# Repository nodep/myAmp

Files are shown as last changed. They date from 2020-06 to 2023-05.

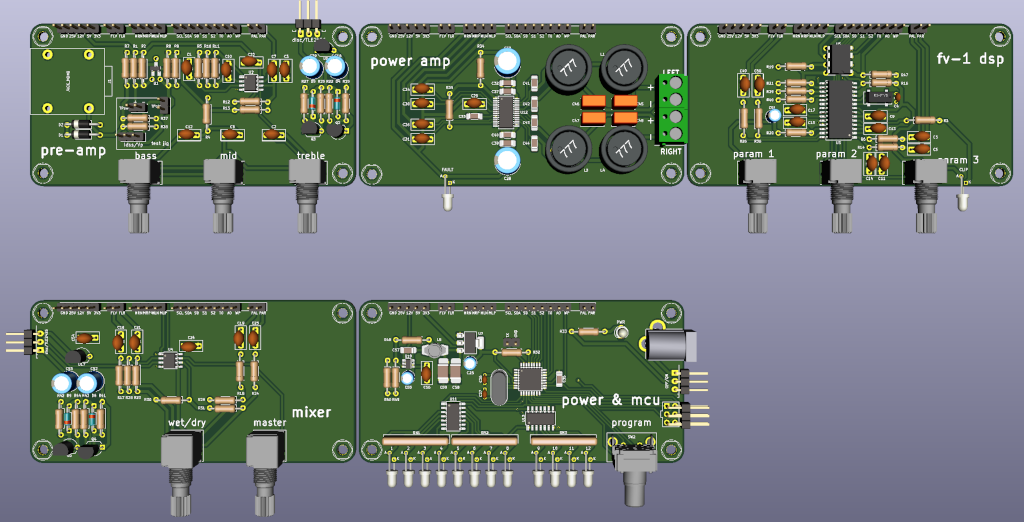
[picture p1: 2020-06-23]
docs/3drender.png

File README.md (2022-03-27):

# modulo2

What started as an idea to upgrade the guts of a practice guitar amplifier (Marshall Valvestate 8010), has evolved into a stereo guitar amplifier with effects. The current prototype is housed in a guitar pedal box (119 x 93.5 x 56.5mm). It has a modular design with the preamp, the effects board, and a stereo power amp. These modules are split into their own PCBs.

### The preamp

It is based on ESP's project 27 (https://sound-au.com/project27.htm). I have only used the preamp from this project and I have made a few changes:

- The overdrive section is changed to work as protection and limit the output to 3.3V. This is needed for the inputs of the DSP chip in the effects section (max input of FV-1 is 3.3V).
- The zener diode rail splitter is changed to a TL2426. Reasons being a smaller footprint and much lower power consumption.
- The total gain has been reduced on every stage.
- The tone control values have changed to a more Fender-like sound.

### The effects

The effects sections is based on a Spin semiconductor's FV-1 DSP chip. The chip has 8 built-in effects and the ability to read 8 more effects from an external EEPROM. This was extended using a microcontroller (ATmega328p) to up to 50 external effects which are read from the microcontroller's flash memory. The board also has a dry/wet mixer, a master volume. The microcontroller has a driverless USB bootloader which allows easier firmware updates and DSP program modification. A rotary encoder allows for FV-1 program selection and changing the input clock frequency of the FV-1. Some of the FV-1 programs work as a mono input and produce a stereo output with one channel outputing a slightly different signal to the other creating a stereo effect from a mono preamp input. The microcontroller oversees the power section to avoid audible pops during the power-up and power-down.

### The power amp

The power section is based on a TPA3220 in a stereo configuration. I have not tested it fully yet, but it should be able to output up to 60W into 4Ω per channel. It is a Class-D amp bringing high efficiency (around 90%) and very low distortion and noise. The TPA3220 chip has an integrated preamp with a selectable gain (4 distinct levels) making the full range of the master volume useful for quiter practice and louder performance levels.

The PCBs for the final prototype have been send to the fab.

Stay tuned for results!

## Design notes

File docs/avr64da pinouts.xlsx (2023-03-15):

VQFN64 TQFP64 | VQFN48 TQFP48 | VQFN32 TQFP32 | SPDIP28 SOIC28 SSOP28 | Pin name | Special | ADC0 | PTC | ACn | DAC0 | ZCDn | USARTn | SPIn | TWIn | TCA0 | TCA1 | TCBn | TCDn | EVSYS | CCL-LUTn
62 | 44 | 30 | 22 | PA0 | EXTCLK |  | X0/Y0 |  |  |  | 0,TxD |  |  | WO0 |  |  |  |  | 0,IN0
63 | 45 | 31 | 23 | PA1 |  |  | X1/Y1 |  |  |  | 0,RxD |  |  | WO1 |  |  |  |  | 0,IN1
64 | 46 | 32 | 24 | PA2 | TWI |  | X2/Y2 |  |  |  | 0,XCK |  | 0,SDA(H) | WO2 |  | 0,WO |  | EVOUTA | 0,IN2
1 | 47 | 1 | 25 | PA3 | TWI |  | X3/Y3 |  |  |  | 0,XDIR |  | 0,SCL(H) | WO3 |  | 1,WO |  |  | 0,OUT
2 | 48 | 2 | 26 | PA4 |  |  | X4/Y4 |  |  |  | 0,TxD (alt) | 0,MOSI |  | WO4 |  |  | 0,WOA
3 | 1 | 3 | 27 | PA5 |  |  | X5/Y5 |  |  |  | 0,RxD (alt) | 0,MISO |  | WO5 |  |  | 0,WOB
4 | 2 | 4 | 28 | PA6 |  |  | X6/Y6 |  |  |  | 0,XCK (alt) | 0,SCK |  |  |  |  | 0,WOC |  | 0,OUT (alt)
5 | 3 | 5 | 1 | PA7 | CLKOUT |  | X7/Y7 | 0,OUT 1,OUT 2,OUT |  | 0,OUT 1,OUT 2,OUT | 0,XDIR (alt) | 0,SS |  |  |  |  | 0,WOD | EVOUTA (alt)
6 |  |  |  | VDD
7 |  |  |  | GND
8 | 4 |  |  | PB0 |  |  | X8/Y8 |  |  |  | 3,TxD |  |  | WO0 (alt) | WO0 |  |  |  | 4,IN0
9 | 5 |  |  | PB1 |  |  | X9/Y9 |  |  |  | 3,RxD |  |  | WO1 (alt) | WO1 |  |  |  | 4,IN1
10 | 6 |  |  | PB2 |  |  | X10/Y10 |  |  |  | 3,XCK |  | 1,SDA(H) (alt) | WO2 (alt) | WO2 |  |  | EVOUTB | 4,IN2
11 | 7 |  |  | PB3 |  |  | X11/Y11 |  |  |  | 3,XDIR |  | 1,SCL(H) (alt) | WO3 (alt) | WO3 |  |  |  | 4,OUT
12 | 8 |  |  | PB4 |  |  | X12/Y12 |  |  |  | 3,TxD (alt) | 1,MOSI (alt) |  | WO4 (alt) | WO4 | 2,WO (alt) | 0,WOA (alt)
13 | 9 |  |  | PB5 |  |  | X13/Y13 |  |  |  | 3,RxD (alt) | 1,MISO (alt) |  | WO5 (alt) | WO5 | 3,WO | 0,WOB (alt)
14 |  |  |  | PB6 |  |  | X14/Y14 |  |  |  | 3,XCK (alt) | 1,SCK (alt) | 1,SDA(C) (alt) |  |  |  | 0,WOC (alt) |  | 4,OUT (alt)
15 |  |  |  | PB7 |  |  | X15/Y15 |  |  |  | 3,XDIR (alt) | 1,SS (alt) | 1,SCL(C) (alt) |  |  |  | 0,WOD (alt) | EVOUTB (alt)
16 | 10 | 6 | 2 | PC0 |  |  |  |  |  |  | 1,TxD | 1,MOSI |  | WO0 (alt) |  | 2,WO |  |  | 1,IN0
17 | 11 | 7 | 3 | PC1 |  |  |  |  |  |  | 1,RxD | 1,MISO |  | WO1 (alt) |  | 3,WO (alt) |  |  | 1,IN1
18 | 12 | 8 | 4 | PC2 | TWI |  |  |  |  |  | 1,XCK | 1,SCK | 0,SDA(H) (alt) | WO2 (alt) |  |  |  | EVOUTC | 1,IN2
19 | 13 | 9 | 5 | PC3 | TWI |  |  |  |  |  | 1,XDIR | 1,SS | 0,SCL(H) (alt) | WO3 (alt) |  |  |  |  | 1,OUT
20 | 14 |  |  | VDD
21 | 15 |  |  | GND
22 | 16 |  |  | PC4 |  |  |  |  |  |  | 1,TxD (alt) | 1,MOSI (alt) |  | WO4 (alt) | WO0 (alt)
23 | 17 |  |  | PC5 |  |  |  |  |  |  | 1,RxD (alt) | 1,MISO (alt) |  | WO5 (alt) | WO1 (alt)
24 | 18 |  |  | PC6 |  |  |  | 0,OUT (alt) 1,OUT (alt) 2,OUT (alt) |  |  | 1,XCK (alt) | 1,SCK (alt) | 0,SDA(C) |  | WO2 (alt) | 4,WO (alt) |  |  | 1,OUT (alt)
25 | 19 |  |  | PC7 |  |  |  |  |  | 0,OUT (alt) 1,OUT (alt) 2,OUT (alt) | 1,XDIR (alt) | 1,SS (alt) | 0,SCL(C) |  |  |  |  | EVOUTC (alt)
26 | 20 | 10 | 6 | PD0 |  | AIN0 | X16/Y16 | 0,AINN1 1,AINN1 2,AINN1 |  |  |  |  |  | WO0 (alt) |  |  |  |  | 2,IN0
27 | 21 | 11 | 7 | PD1 |  | AIN1 | X17/Y17 |  |  | 0,ZCIN |  |  |  | WO1 (alt) |  |  |  |  | 2,IN1
28 | 22 | 12 | 8 | PD2 |  | AIN2 | X18/Y18 | 0,AINP0 1,AINP0 2,AINP0 |  |  |  |  |  | WO2 (alt) |  |  |  | EVOUTD | 2,IN2
29 | 23 | 13 | 9 | PD3 |  | AIN3 | X19/Y19 | 0,AINN0 1,AINP1 |  |  |  |  |  | WO3 (alt) |  |  |  |  | 2,OUT
30 | 24 | 14 | 10 | PD4 |  | AIN4 | X20/Y20 | 1,AINP2 2,AINP1 |  |  |  |  |  | WO4 (alt)
31 | 25 | 15 | 11 | PD5 |  | AIN5 | X21/Y21 | 1,AINN0 |  |  |  |  |  | WO5 (alt)
32 | 26 | 16 | 12 | PD6 |  | AIN6 | X22/Y22 | 0,AINP3 1,AINP3 2,AINP3 0,AINN2 | VOUT |  |  |  |  |  |  |  |  |  | 2,OUT (alt)
33 | 27 | 17 | 13 | PD7 | VREFA | AIN7 | X23/Y23 | 1,AINN2 2,AINN0/AINN2 |  |  |  |  |  |  |  |  |  | EVOUTD (alt)
34 | 28 | 18 | 14 | AVDD
35 | 29 | 19 | 15 | GND
36 | 30 |  |  | PE0 |  | AIN8 | X24/Y24 | 0,AINP1 |  |  | 4,TxD | 0,MOSI (alt) |  | WO0 (alt)
37 | 31 |  |  | PE1 |  | AIN9 | X25/Y25 | 2,AINP2 |  |  | 4,RxD | 0,MISO (alt) |  | WO1 (alt)
38 | 32 |  |  | PE2 |  | AIN10 | X26/Y26 | 0,AINP2 |  |  | 4,XCK | 0,SCK (alt) |  | WO2 (alt) |  |  |  | EVOUTE
39 | 33 |  |  | PE3 |  | AIN11 | X27/Y27 |  |  | 1,ZCIN | 4,XDIR | 0,SS (alt) |  | WO3 (alt)
40 |  |  |  | PE4 |  | AIN12 | X28/Y28 |  |  |  | 4,TxD (alt) |  |  | WO4 (alt) | WO0 (alt)
41 |  |  |  | PE5 |  | AIN13 | X29/Y29 |  |  |  | 4,RxD (alt) |  |  | WO5 (alt) | WO1 (alt)
42 |  |  |  | PE6 |  | AIN14 | X30/Y30 |  |  |  | 4,XCK (alt) |  |  |  | WO2 (alt)
43 |  |  |  | PE7 |  | AIN15 | X31/Y31 |  |  | 2,ZCIN | 4,XDIR (alt) |  |  |  |  |  |  | EVOUTE (alt)
44 | 34 | 20 | 16 | PF0 | XTAL32K1 | AIN16 | X32/Y32 |  |  |  | 2,TxD |  |  | WO0 (alt) |  |  | 0,WOA (alt) |  | 3,IN0
45 | 35 | 21 | 17 | PF1 | XTAL32K2 | AIN17 | X33/Y33 |  |  |  | 2,RxD |  |  | WO1 (alt) |  |  | 0,WOB (alt) |  | 3,IN1
46 | 36 | 22 |  | PF2 | TWI | AIN18 | X34/Y34 |  |  |  | 2,XCK |  | 1,SDA(H) | WO2 (alt) |  |  | 0,WOC | EVOUTF | 3,IN2
47 | 37 | 23 |  | PF3 | TWI | AIN19 | X35/Y35 |  |  |  | 2, XDIR |  | 1,SCL(H) | WO3 (alt) |  |  | 0,WOD |  | 3,OUT
48 | 38 | 24 |  | PF4 |  | AIN20 | X36/Y36 |  |  |  | 2, TxD |  |  | WO4 (alt) |  | 0,WO (alt)
49 | 39 | 25 |  | PF5 |  | AIN21 | X37/Y37 |  |  |  | 2, RxD |  |  | WO5 (alt) |  | 1,WO (alt)
50 | 40 | 26 | 18 | PF6 | RESET
51 | 41 | 27 | 19 | UPDI
52 |  |  |  | PG0 |  |  | X40/Y40 |  |  |  | 5,TxD |  |  | WO0 (alt) | WO0 (alt) |  |  |  | 5,IN0
53 |  |  |  | PG1 |  |  | X41/Y41 |  |  |  | 5,RxD |  |  | WO1 (alt) | WO1 (alt) |  |  |  | 5,IN1
54 |  |  |  | PG2 |  |  | X42/Y42 |  |  |  | 5,XCK |  |  | WO2 (alt) | WO2 (alt) |  |  | EVOUTG | 5,IN2
55 |  |  |  | PG3 |  |  | X43/Y43 |  |  |  | 5,XDIR |  |  | WO3 (alt) | WO3 (alt) | 4,WO |  |  | 5,OUT
56 | 42 | 28 | 20 | VDD
57 | 43 | 29 | 21 | GND
58 |  |  |  | PG4 |  |  | X44/Y44 |  |  |  | 5,TxD (alt) | 0,MOSI (alt) |  | WO4 (alt) | WO4 (alt) |  | 0,WOA (alt)
59 |  |  |  | PG5 |  |  | X45/Y45 |  |  |  | 5,RxD (alt) | 0,MISO (alt) |  | WO5 (alt) | WO5 (alt) |  | 0,WOB (alt)
60 |  |  |  | PG6 |  |  | X46/Y46 |  |  |  | 5,XCK (alt) | 0,SCK (alt) |  |  |  |  | 0,WOC (alt) |  | 5,OUT (alt)
61 |  |  |  | PG7 |  |  | X47/Y47 |  |  |  | 5,XDIR (alt) | 0,SS (alt) |  |  |  |  | 0,WOD (alt) | EVOUTG (alt)

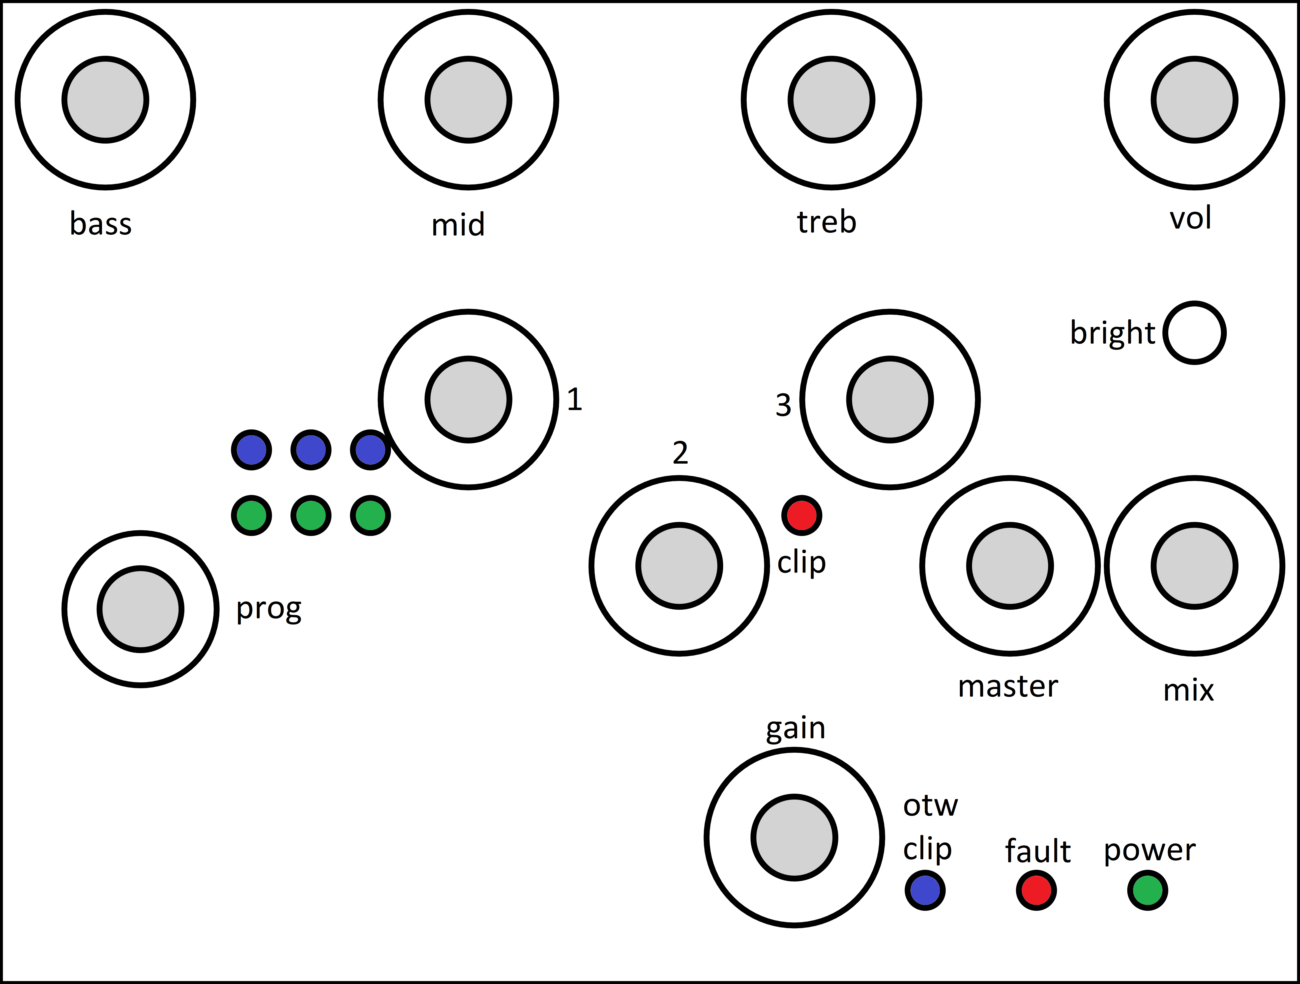
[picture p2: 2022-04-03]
docs/in_pedal_render.png

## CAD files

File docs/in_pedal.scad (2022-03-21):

$fn = 80;

pcb_thick = 1.6;
pcb_width = 105;
pcb_height = 47;
led_r = 3;
led_l = 8;

pot_shaft = 7;
pot_shaft_offset = 6.3;
pot_shaft_len = 6;
pot_depth = 7.05;
pot_height = 11.3;
pot_width = 9.5;
pot_knob_r = 15;

switch_shaft = 5;
switch_shaft_offset = 12;
switch_shaft_len = 12;

rotenc_shaft_r = 7;
rotenc_shaft_l = 15;
rotenc_knob_r = 13;

gain_sel_shaft_r = 7;
gain_sel_shaft_l = 15;

module pcb_blank()
{
	cube([pcb_width, pcb_height, pcb_thick]);
}

module pot_up(pos)
{
	translate([pos - pot_width/2, pcb_height - pot_depth, pcb_thick])
	{
		cube([pot_width, pot_depth, pot_height]);
		
		translate([pot_width/2, pot_shaft_len + pot_depth, pot_shaft_offset])
			rotate([90, 0, 0])
				difference()
				{
					cylinder(pot_shaft_len, pot_knob_r / 2, pot_knob_r / 2);
					cylinder(pot_shaft_len, pot_shaft / 2, pot_shaft / 2);
				}
	}
}

module pot_down(pos)
{
	translate([pos - pot_width/2, pcb_height - pot_depth, -pot_height])
	{
		cube([pot_width, pot_depth, pot_height]);
		
		translate([pot_width/2, pot_shaft_len + pot_depth, pot_height - pot_shaft_offset])
			rotate([90, 0, 0])
				difference()
				{
					cylinder(pot_shaft_len, pot_knob_r / 2, pot_knob_r / 2);
					cylinder(pot_shaft_len, pot_shaft / 2, pot_shaft / 2);
				}
	}
}

module switch_down(pos)
{
	translate([pos, pcb_height + switch_shaft_len / 2, -switch_shaft_offset])
		rotate([90, 0, 0])
			cylinder(switch_shaft_len, switch_shaft / 2, switch_shaft / 2);
}

module led_up(x, off)
{
	translate([x, pcb_height + led_l / 2, pcb_thick + off])
		rotate([90, 0, 0])
			cylinder(led_l, led_r / 2, led_r / 2);
}

module led_down(x, off)
{
	translate([x, pcb_height + led_l / 2, -off])
		rotate([90, 0, 0])
			cylinder(led_l, led_r / 2, led_r / 2);
}

module rotenc_shaft_down(x)
{
	translate([x, pcb_height + rotenc_shaft_l / 2, -10])
		rotate([90, 0, 0])
			difference()
			{
				cylinder(rotenc_shaft_l, rotenc_knob_r / 2, rotenc_knob_r / 2);
				cylinder(rotenc_shaft_l, rotenc_shaft_r / 2, rotenc_shaft_r / 2);
			}
}

module gain_sel_shaft_down(x)
{
	translate([x, pcb_height + gain_sel_shaft_l / 2, pcb_thick + 6.5])
		rotate([90, 0, 0])
			difference()
			{
				cylinder(gain_sel_shaft_l, pot_knob_r / 2, pot_knob_r / 2);
				cylinder(gain_sel_shaft_l, gain_sel_shaft_r / 2, gain_sel_shaft_r / 2);
			}
}

module pcb_pa27()
{
	pcb_blank();

	pot_up( 6);
	pot_up(37);
	pot_up(68);
	pot_up(99);
	
	switch_down(6);
}

module pcb_fv1()
{
	pcb_blank();

	pot_down(6);
	pot_down(21.755);
	pot_up(32);
	pot_down(50);
	pot_up(68);
	
	// clip
	led_down(39.535, 2);
	
	// program
	led_down(76.365, 2);
	led_down(81.445, 2);
	led_down(86.525, 2);
	led_up(76.365, 2);
	led_up(81.445, 2);
	led_up(86.525, 2);
	
	rotenc_shaft_down(96);
}

module pcb_powamp()
{
	pcb_blank();
	
	led_up(10, 2);
	led_up(19.5, 2);
	led_up(29, 2);

	gain_sel_shaft_down(40.17);
}

projection(cut = true)
{
	translate([-20, 0, 0])
		difference()
		{
			translate([-3, -42, -0.8])
				cube([111, 84, pcb_thick]);

			rotate([90, 0, 0])
				translate([0, -48, 0])
				{
					translate([0, 0, 24 + 1.6])
						pcb_pa27();

					translate([0, 0, 0])
						pcb_fv1();

					translate([0, 0, -36 - 1.6])
						pcb_powamp();
				}
		}
}

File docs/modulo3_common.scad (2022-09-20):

module top()
{
	difference()
	{
		top_offset = sin(angle) * thick;

		rotate([-90, 0, 0])
			linear_extrude(baffle_size + thick*2)
				polygon([	[0, 0],
							[0, thick],
							[in_depth - offset, thick],
							[in_depth - offset - top_offset, 0]]);

		translate([0, thick + (baffle_size - ctr_width) / 2, -1 - thick])
			cube([ctr_depth, ctr_width, thick + 2]);
	}
}

module baffle()
{
	difference()
	{
		cube([baffle_thick, baffle_size, baffle_size]);

		translate([-1, baffle_size/2, baffle_size/2])
			rotate([0, 90, 0])
				cylinder(baffle_thick + 2, speaker_hole, speaker_hole);
	}
}

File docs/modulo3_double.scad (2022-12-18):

include <modulo3_common.scad>

$fn = 120;

thick = 18;
baffle_thick = 10;
baffle_size = 330;
in_depth = 280;
speaker_hole = 231/2;

ctr_width = 200;
ctr_depth = 90;
ctr_height = 70;

angle = 15;

up_back_height = 140;
low_back_height = 140;

up_height	= cos(angle) * baffle_size;
offset		= sin(angle) * baffle_size;
in_height	= up_height + baffle_size;

vol_side	= (in_height * in_depth - up_height * offset / 2) * thick;
vol_top		= ((in_depth - offset) * (baffle_size + thick*2) - (ctr_depth * ctr_width)) * thick;
vol_bottom	= in_depth * (baffle_size + thick*2) * thick;
vol_baffle	= (baffle_size * baffle_size - speaker_hole * speaker_hole * 3.1416) * baffle_thick;
vol_separat	= in_depth * baffle_size * baffle_thick;
vol_up_back	= (baffle_size * up_back_height - ctr_width * ctr_height) * thick;
vol_low_back = baffle_size * low_back_height * thick;
vol_all		= (vol_side*2 + vol_top + vol_bottom + vol_baffle * 2 + vol_separat + vol_low_back + vol_up_back) / 1000;

echo("******************************");
echo("volume cm3 = ", vol_all);
echo("pine kg = ", vol_all * 0.52 / 1000);
echo("size: ", baffle_size + thick*2, in_height + thick*2, in_depth);

translate([0, baffle_size + thick*2, 0])
	side();

translate([0, thick, 0])
	side();

// bottom
translate([0, 0, -thick])
	cube([in_depth, baffle_size + thick*2, thick]);

translate([0, 0, in_height + thick])
	top();

// lower baffle
translate([in_depth - baffle_thick*2, thick, 0])
	baffle();

// upper baffle
translate([in_depth - baffle_thick*2, thick, baffle_size - 1.5])
	rotate([0, -angle, 0])
		baffle();

// middle separator
translate([0, thick, baffle_size])
	cube([in_depth - thick, baffle_size, baffle_thick]);

// lower back
translate([0, thick, 0])
	cube([thick, baffle_size, low_back_height]);

translate([0, thick, in_height - up_back_height])
	upper_back();

module upper_back()
{
	difference()
	{
		cube([thick, baffle_size, up_back_height]);
		
		translate([-1, (baffle_size - ctr_width) / 2, up_back_height - ctr_height])
			cube([thick + 2, ctr_width, ctr_height]);
	}
}

module side()
{
	rotate([90, 0, 0])
		linear_extrude(thick)
			polygon([	[0, 0],
						[in_depth, 0],
						[in_depth, baffle_size],
						[in_depth - offset, in_height],
						[0, in_height]]);
}

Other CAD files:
docs/modulo3_single.scad

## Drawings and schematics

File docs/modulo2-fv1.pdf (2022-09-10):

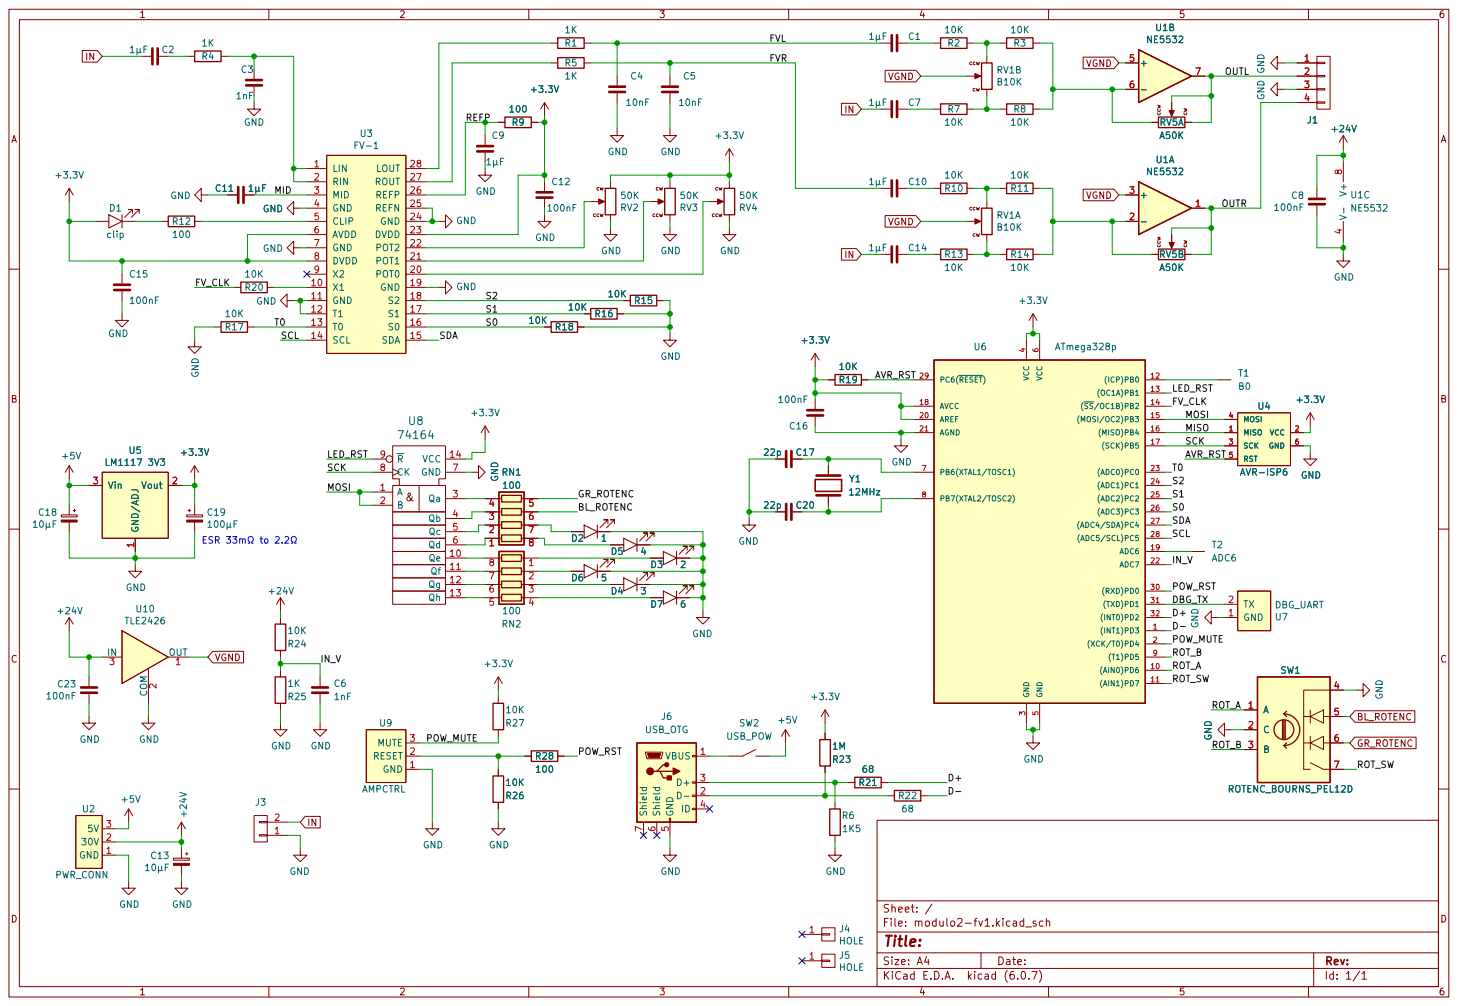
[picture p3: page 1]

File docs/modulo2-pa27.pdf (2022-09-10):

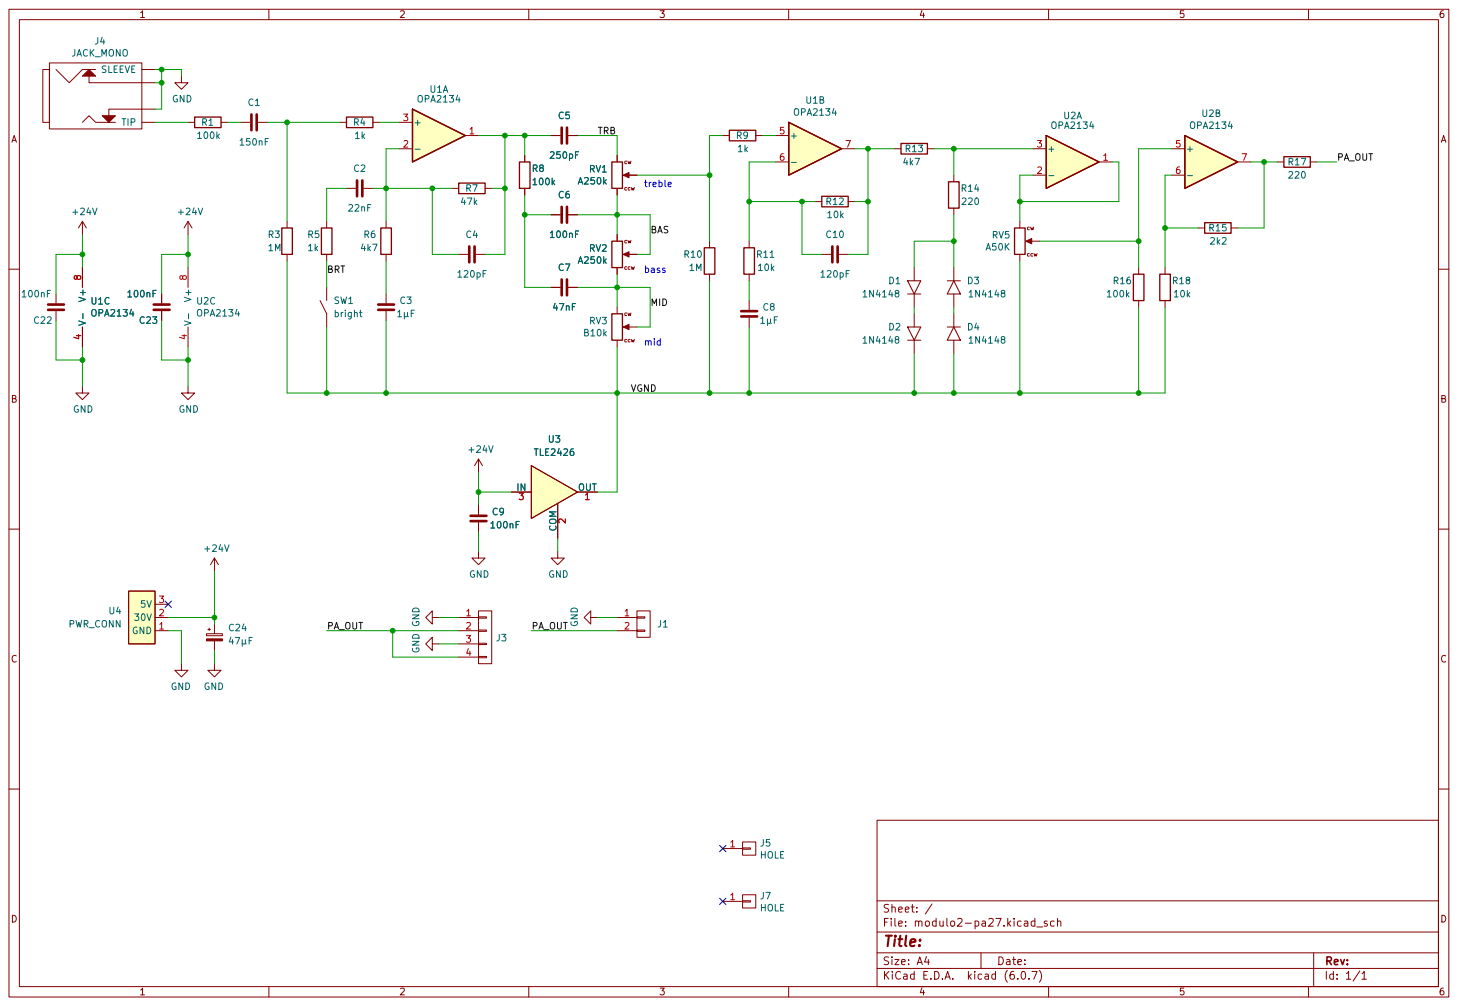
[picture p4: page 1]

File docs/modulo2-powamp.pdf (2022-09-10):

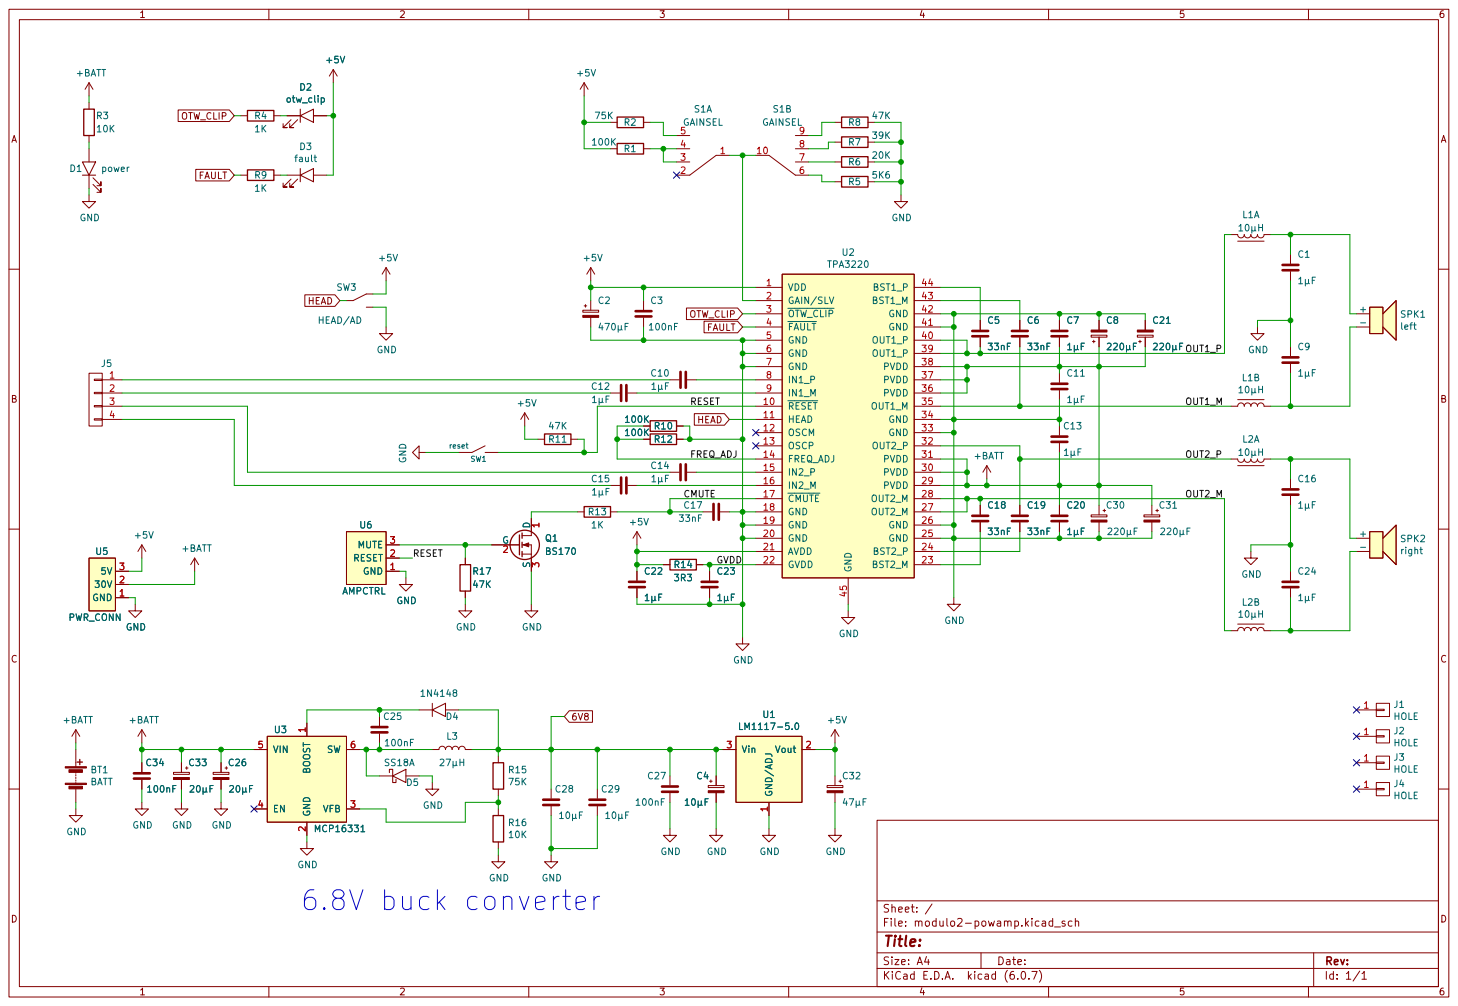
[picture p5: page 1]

2 VFB 3 EN 4 VIN 5 SW 6 U3 MCP16331 C34

2 VFB 3 EN 4 VIN 5 SW 6 C34

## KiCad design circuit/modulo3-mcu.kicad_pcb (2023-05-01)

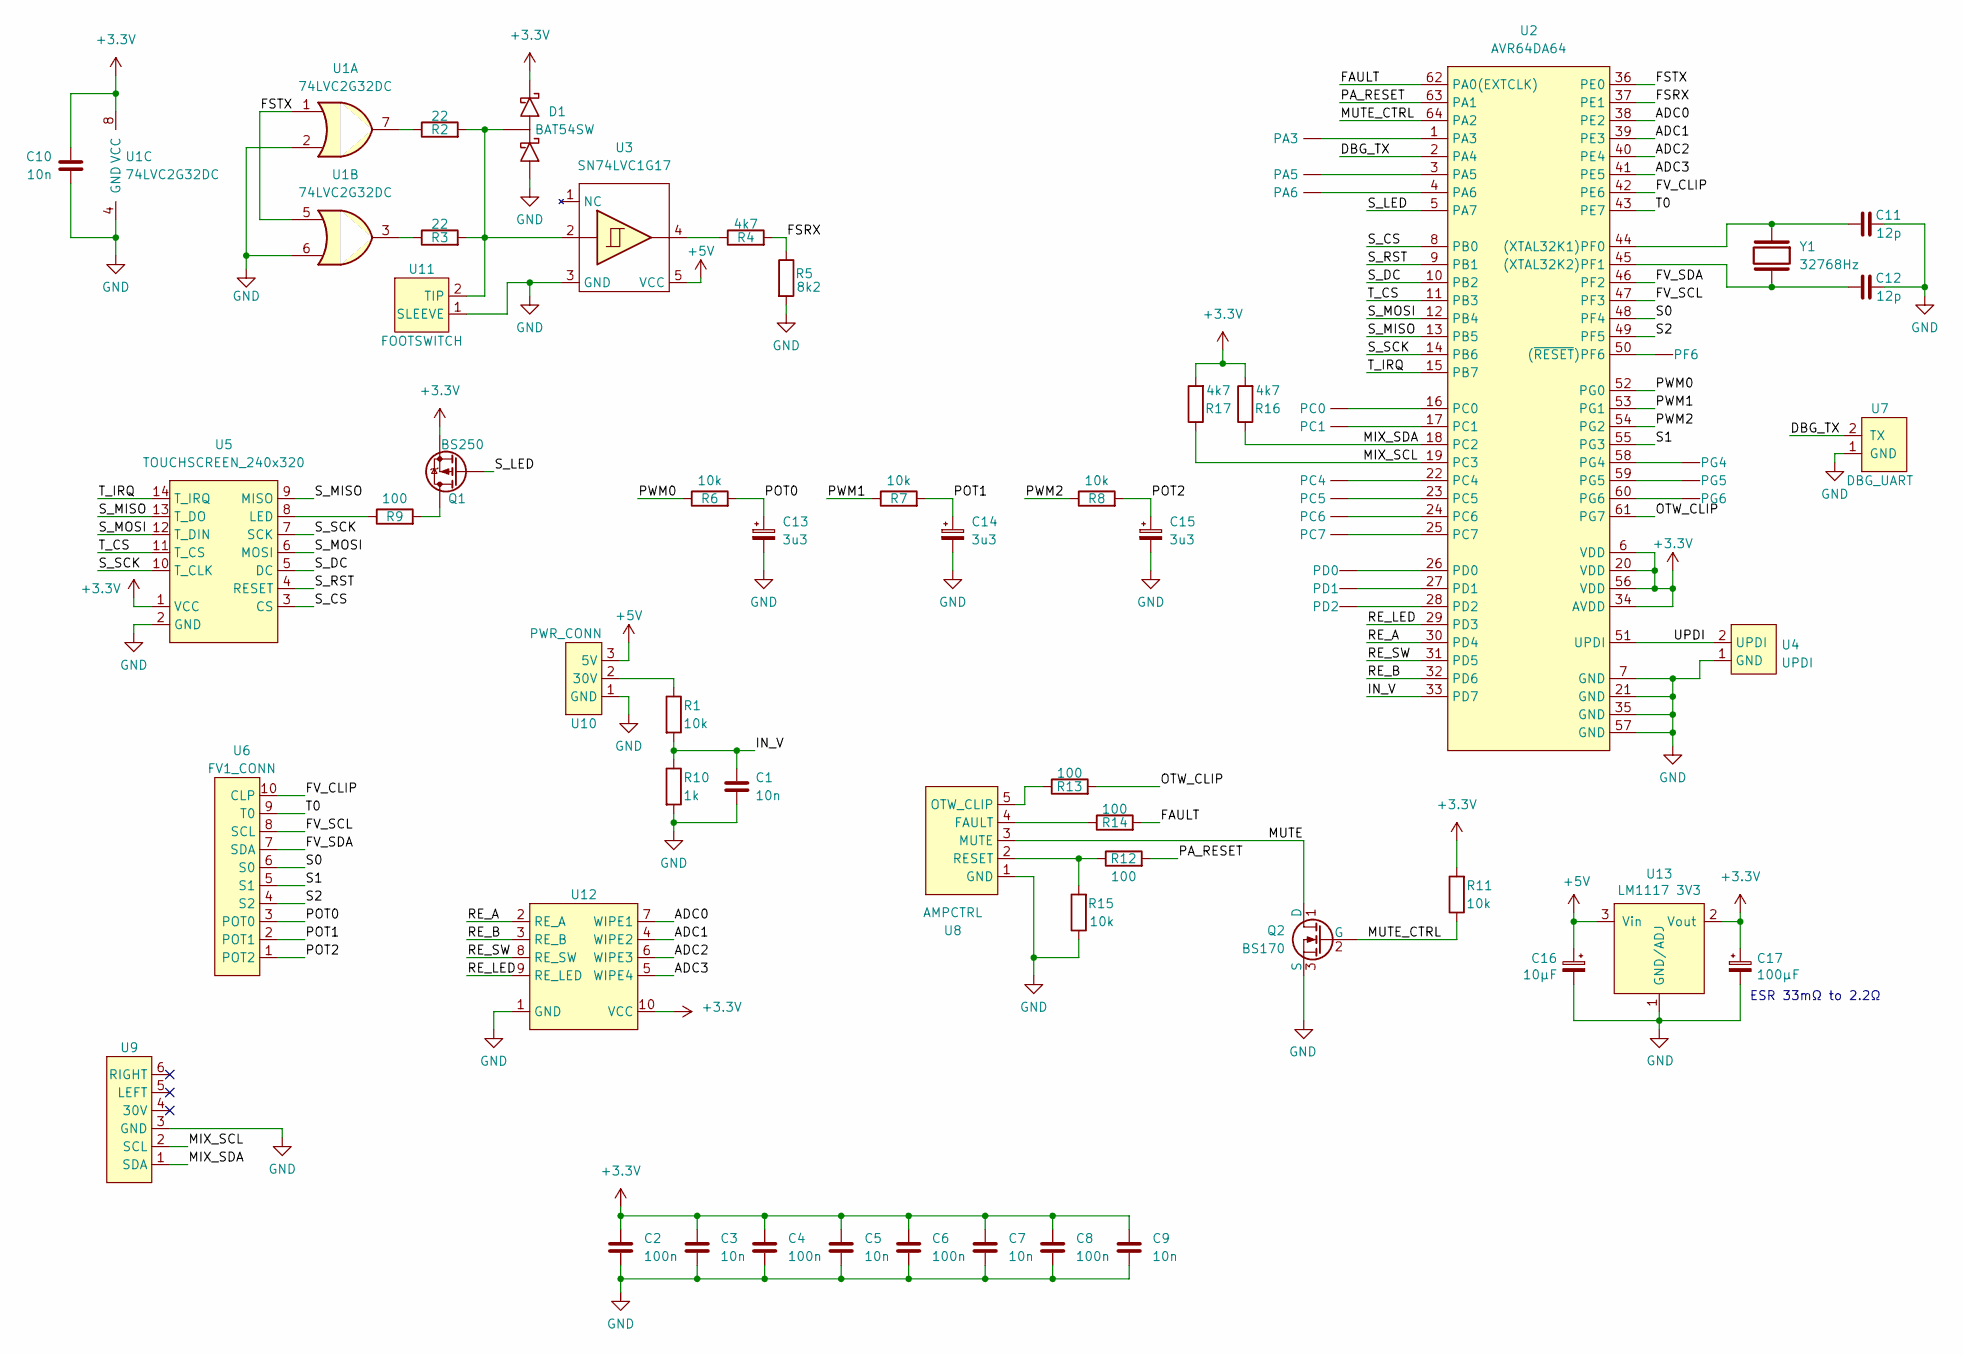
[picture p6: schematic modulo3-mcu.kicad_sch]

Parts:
C1, C3, C5, C7, C9, C10: 10n; C_1206
C2, C4, C6, C8: 100n; C_1206
C11, C12: 12p; C_1206
C13, C14, C15: 3u3; CPOL_D4_P1.5
C16: 10µF; CPOL_D4_P1.5
C17: 100µF; CPOL_D6.3_P2.5
D1: BAT54SW; SOT-23
Q1: BS250; TO-92_Inline_Wide
Q2: BS170; TO-92_Inline_Wide
R1, R6, R7, R8, R11, R15: 10k; R_10MM
R2, R3: 22; R_10MM
R4, R16, R17: 4k7; R_10MM
R5: 8k2; R_10MM
R9, R12, R13, R14: 100; R_10MM
R10: 1k; R_10MM
T1: PA3; TestPad
T2: PD2; TestPad
T3: PA6; TestPad
T4: PC0; TestPad
T5: PC1; TestPad
T6: PG5; TestPad
T7: PG4; TestPad
T8: PF6; TestPad
T9: PA5; TestPad
T10: PD1; TestPad
T11: PD0; TestPad
T12: PC7; TestPad
T13: PG6; TestPad
T14: PC4; TestPad
T15: PC5; TestPad
T16: PC6; TestPad
U1: 74LVC2G32DC; VSSOP-8_2.4x2.1mm_P0.5mm
U2: AVR64DA64; TQFP-64_10x10mm_P0.5mm
U3: SN74LVC1G17; SOT-23-5
U4: UPDI; UDPI
U5: TOUCHSCREEN_240x320; TOUCHSCREEN_2.8
U6: FV1_CONN
U7: DBG_UART
U8: AMPCTRL
U9: PREAMP_CONN
U10: PWR_CONN
U11: FOOTSWITCH; EXT_JACK
U12: KNOBS
U13: LM1117 3V3; SOT-223
Y1: 32768Hz; QUARTZ_85SMX

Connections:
+3.3V: C2.1, C3.1, C4.1, C5.1, C6.1, C7.1, C8.1, C9.1, C10.1, C17.1, D1.2, Q1.3 (S), R11.2, R16.2, R17.2, U1.8 (VCC), U2.6 (VDD), U2.20 (VDD), U2.34 (AVDD), U2.56 (VDD), U5.1 (VCC), U12.10 (VCC), U13.2 (Vout)
+5V: C16.1, U3.5 (VCC), U10.3 (5V), U13.3 (Vin)
/ADC0: U2.38 (PE2), U12.7 (WIPE1)
/ADC1: U2.39 (PE3), U12.4 (WIPE2)
/ADC2: U2.40 (PE4), U12.6 (WIPE3)
/ADC3: U2.41 (PE5), U12.5 (WIPE4)
/DBG_TX: U2.2 (PA4), U7.2 (TX)
/FAULT: R14.2, U2.62 (PA0(EXTCLK))
/FSRX: R4.2, R5.1, U2.37 (PE1)
/FSTX: U1.1, U1.5, U2.36 (PE0)
/FV_CLIP: U2.42 (PE6), U6.10 (CLP)
/FV_SCL: U2.47 (PF3), U6.8 (SCL)
/FV_SDA: U2.46 (PF2), U6.7 (SDA)
/IN_V: C1.1, R1.2, R10.1, U2.33 (PD7)
/MIX_SCL: R17.1, U2.19 (PC3), U9.2 (SCL)
/MIX_SDA: R16.1, U2.18 (PC2), U9.1 (SDA)
/MUTE: Q2.1 (D), U8.3 (MUTE)
/MUTE_CTRL: Q2.2 (G), R11.1, U2.64 (PA2)
/OTW_CLIP: R13.2, U2.61 (PG7)
/PA_RESET: R12.2, U2.63 (PA1)
/POT0: C13.1, R6.2, U6.3 (POT0)
/POT1: C14.1, R7.2, U6.2 (POT1)
/POT2: C15.1, R8.2, U6.1 (POT2)
/PWM0: R6.1, U2.52 (PG0)
/PWM1: R7.1, U2.53 (PG1)
/PWM2: R8.1, U2.54 (PG2)
/RE_A: U2.30 (PD4), U12.2 (RE_A)
/RE_B: U2.32 (PD6), U12.3 (RE_B)
/RE_LED: U2.29 (PD3), U12.9 (RE_LED)
/RE_SW: U2.31 (PD5), U12.8 (RE_SW)
/S0: U2.48 (PF4), U6.6 (S0)
/S1: U2.55 (PG3), U6.5 (S1)
/S2: U2.49 (PF5), U6.4 (S2)
/S_CS: U2.8 (PB0), U5.3 (CS)
/S_DC: U2.10 (PB2), U5.5 (DC)
/S_LED: Q1.2 (G), U2.5 (PA7)
/S_MISO: U2.13 (PB5), U5.9 (MISO), U5.13 (T_DO)
/S_MOSI: U2.12 (PB4), U5.6 (MOSI), U5.12 (T_DIN)
/S_RST: U2.9 (PB1), U5.4 (RESET)
/S_SCK: U2.14 (PB6), U5.7 (SCK), U5.10 (T_CLK)
/T0: U2.43 (PE7), U6.9 (T0)
/T_CS: U2.11 (PB3), U5.11 (T_CS)
/T_IRQ: U2.15 (PB7), U5.14 (T_IRQ)
/UPDI: U2.51 (UPDI), U4.2 (UPDI)
GND: C1.2, C2.2, C3.2, C4.2, C5.2, C6.2, C7.2, C8.2, C9.2, C10.2, C11.2, C12.2, C13.2, C14.2, C15.2, C16.2, C17.2, D1.1, Q2.3 (S), R5.2, R10.2, R15.1, U1.2, U1.4 (GND), U1.6, U2.7 (GND), U2.21 (GND), U2.35 (GND), U2.57 (GND), U3.3 (GND), U4.1 (GND), U5.2 (GND), U7.1 (GND), U8.1 (GND), U9.3 (GND), U10.1 (GND), U11.1 (SLEEVE), U12.1 (GND), U13.1 (GND/ADJ)
unnamed: Q1.1 (D), R9.2
unnamed: R2.1, U1.7
unnamed: R3.1, U1.3
unnamed: R4.1, U3.4
unnamed: C11.1, U2.44 ((XTAL32K1)PF0), Y1.1
unnamed: C12.1, U2.45 ((XTAL32K2)PF1), Y1.2
unnamed: T8.1, U2.50 ((~RESET)PF6)
unnamed: T1.1, U2.1 (PA3)
unnamed: T9.1, U2.3 (PA5)
unnamed: T3.1, U2.4 (PA6)
unnamed: T4.1, U2.16 (PC0)
unnamed: T5.1, U2.17 (PC1)
unnamed: T14.1, U2.22 (PC4)
unnamed: T15.1, U2.23 (PC5)
unnamed: T16.1, U2.24 (PC6)
unnamed: T12.1, U2.25 (PC7)
unnamed: T11.1, U2.26 (PD0)
unnamed: T10.1, U2.27 (PD1)
unnamed: T2.1, U2.28 (PD2)
unnamed: T7.1, U2.58 (PG4)
unnamed: T6.1, U2.59 (PG5)
unnamed: T13.1, U2.60 (PG6)
unnamed: R9.1, U5.8 (LED)
unnamed: R14.1, U8.4 (FAULT)
unnamed: R13.1, U8.5 (OTW_CLIP)
unnamed: R12.1, R15.2, U8.2 (RESET)
unnamed: R1.1, U10.2 (30V)
unnamed: D1.3, R2.2, R3.2, U3.2, U11.2 (TIP)

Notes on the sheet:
ESR 33mΩ to 2.2Ω

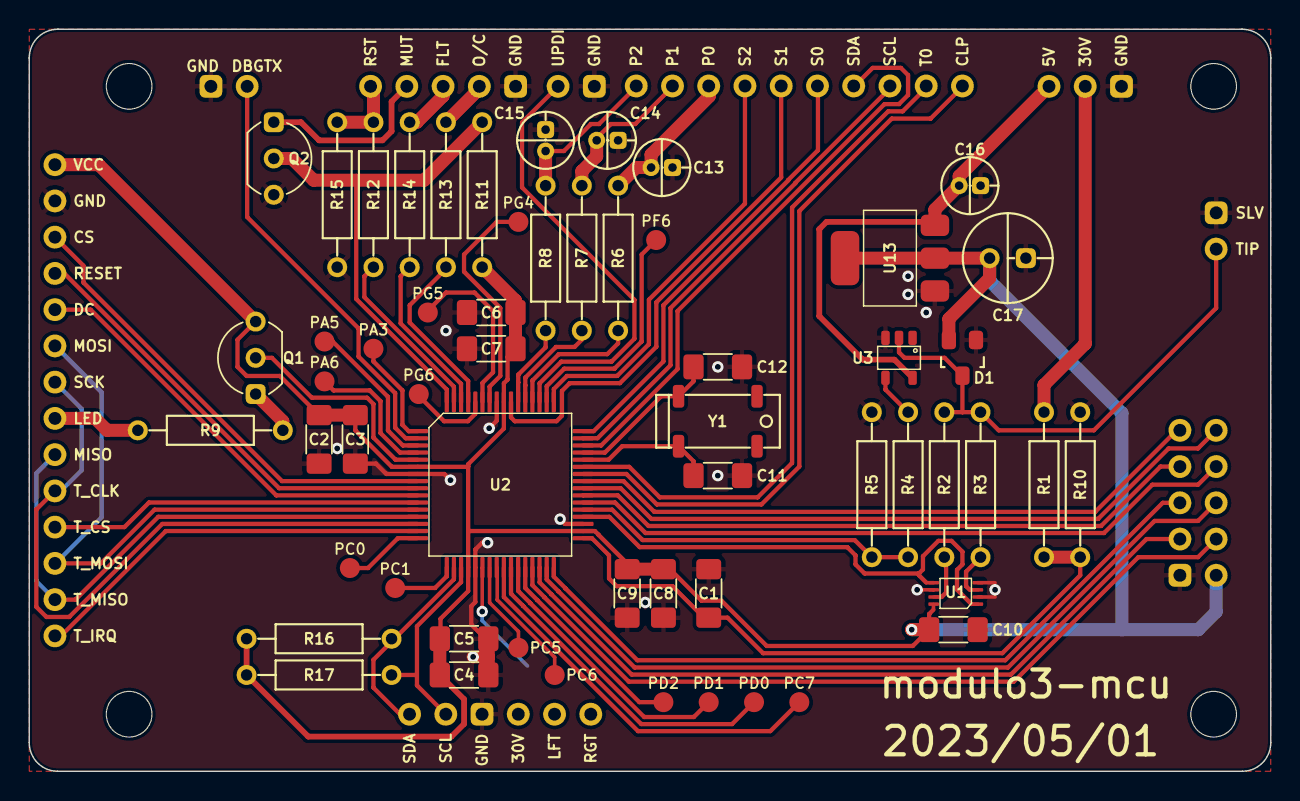
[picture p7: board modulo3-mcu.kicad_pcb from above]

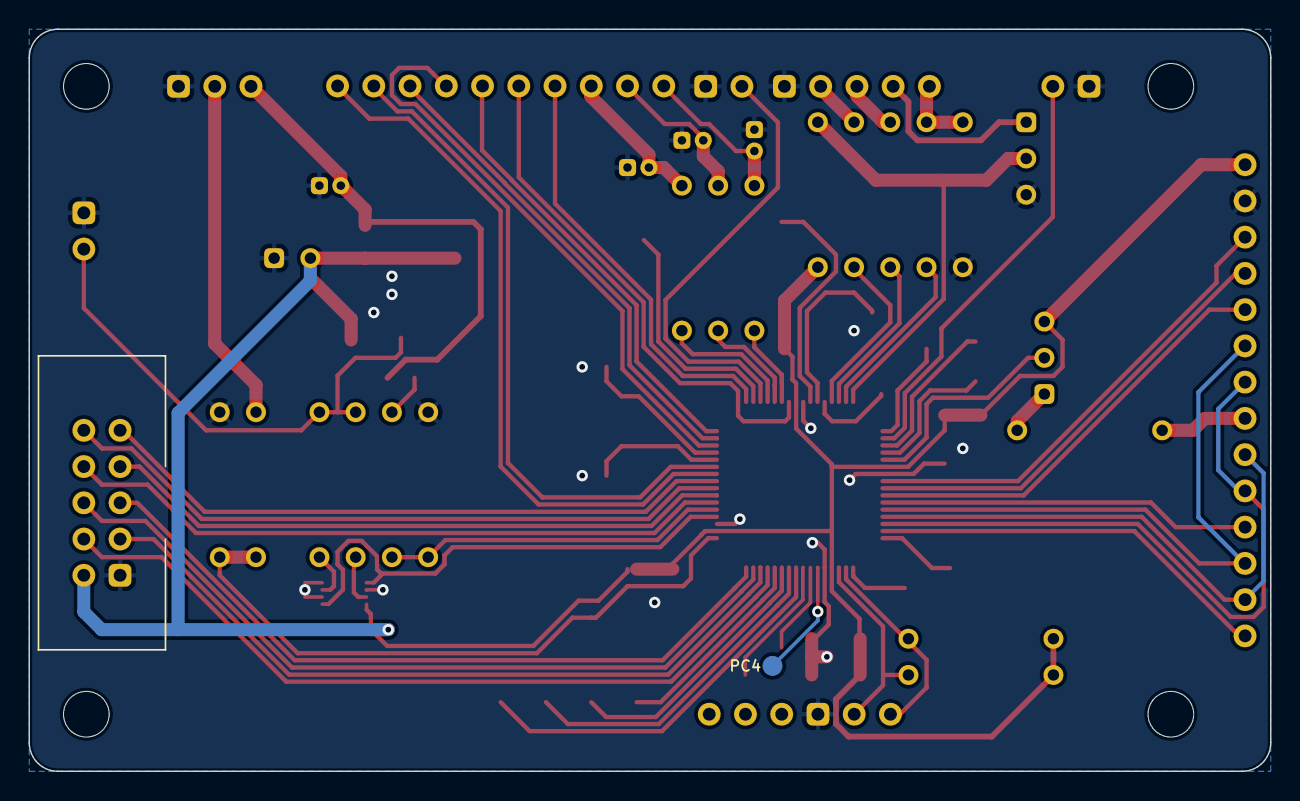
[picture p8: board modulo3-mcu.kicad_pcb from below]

Board: 2 copper layers, 87.0 x 52.0 mm, 67 parts (2 on the bottom side), 73 nets.

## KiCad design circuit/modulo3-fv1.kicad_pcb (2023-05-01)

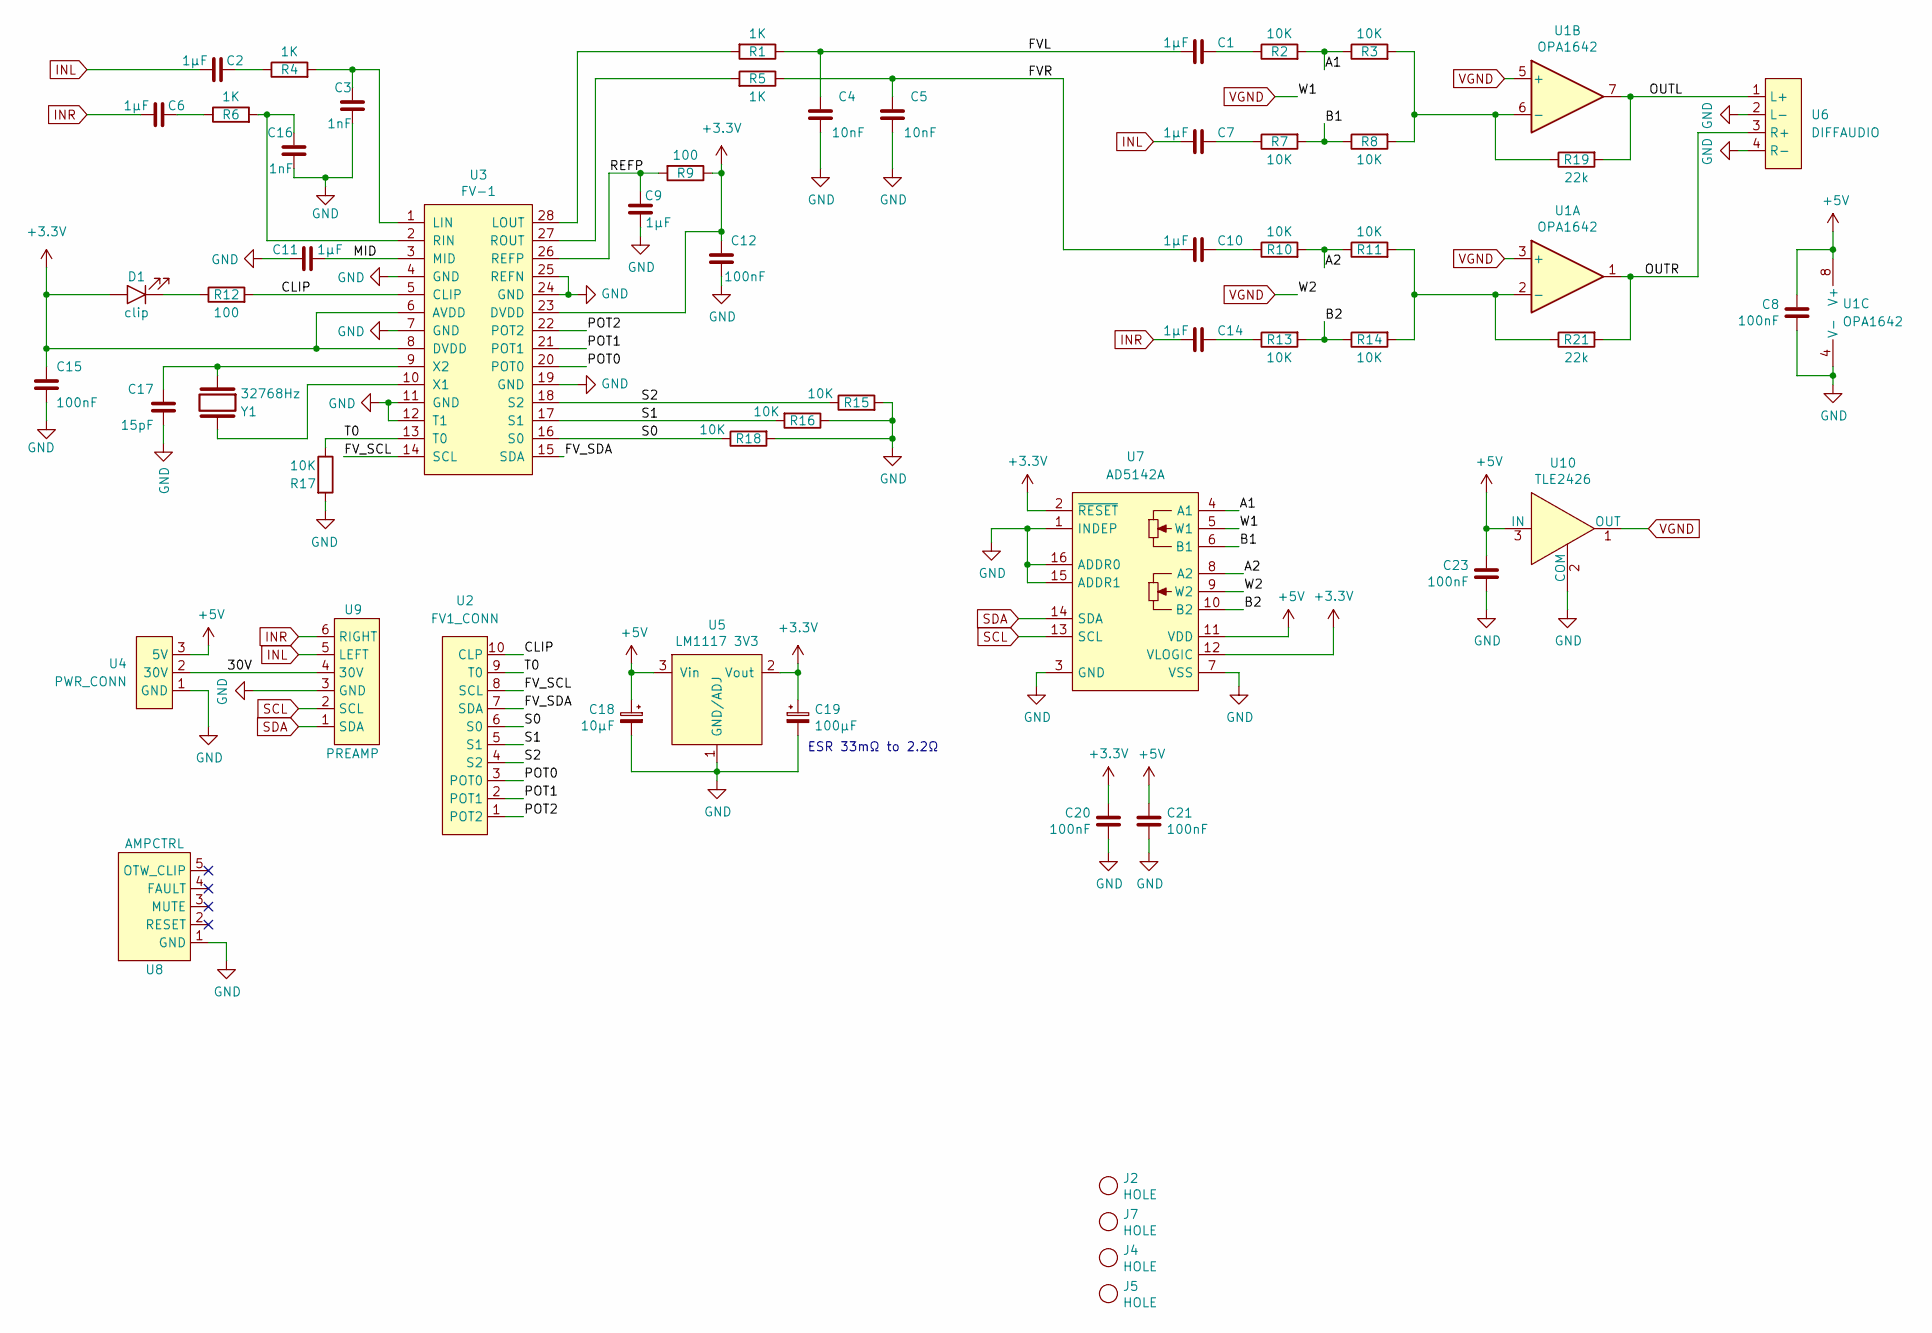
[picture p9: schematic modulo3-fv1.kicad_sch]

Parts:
C1, C2, C6, C7, C10, C14: 1µF; C_FILM_L7.2mm_W5.0mm_P5.00mm
C3, C16: 1nF; C_1206
C4, C5: 10nF; C_1206
C8, C12, C15, C20, C21, C23: 100nF; C_1206
C9, C11: 1µF; C_1206
C17: 15pF; C_1206
C18: 10µF; CPOL_D4_P1.5
C19: 100µF; CPOL_D6.3_P2.5
D1: clip; LED_D3.0mm
J2, J4, J5, J7: HOLE; MountingHole
R1, R4, R5, R6: 1K; R_10MM
R2, R3, R7, R8, R10, R11, R13, R14, R15, R16, R17, R18: 10K; R_10MM
R9, R12: 100; R_10MM
R19, R21: 22k; R_10MM
U1: OPA1642; SOIC-8_3.9x4.9mm_P1.27mm
U2: FV1_CONN
U3: FV-1; SOIC-28_7.5x17.9mm_Pitch1.27mm
U4: PWR_CONN
U5: LM1117 3V3; SOT-223
U6: DIFFAUDIO
U7: AD5142A; TSSOP-16_4.4x5mm_P0.65mm
U8: AMPCTRL
U9: PREAMP; PREAMP_CONN
U10: TLE2426; TO-92_Inline_Wide
Y1: 32768Hz; QUARTZ_85SMX

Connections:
+3V3: C12.1, C15.2, C19.1, C20.2, D1.2 (A), R9.1, U3.6 (AVDD), U3.8 (DVDD), U3.23 (DVDD), U5.2 (Vout), U7.2 (~RESET), U7.12 (VLOGIC)
+5V: C8.2, C18.1, C21.2, C23.2, U1.8 (V+), U4.3 (5V), U5.3 (Vin), U7.11 (VDD), U10.3 (IN)
/30V: U4.2 (30V), U9.4 (30V)
/A1: R2.2, R3.1, U7.4 (A1)
/A2: R10.2, R11.1, U7.8 (A2)
/B1: R7.2, R8.1, U7.6 (B1)
/B2: R13.2, R14.1, U7.10 (B2)
/CLIP: R12.2, U2.10 (CLP), U3.5 (CLIP)
/FVL: C1.1, C4.1, R1.1
/FVR: C5.1, C10.1, R5.1
/FV_SCL: U2.8 (SCL), U3.14 (SCL)
/FV_SDA: U2.7 (SDA), U3.15 (SDA)
/MID: C11.2, U3.3 (MID)
/OUTL: R19.2, U1.7, U6.1 (L+)
/OUTR: R21.2, U1.1, U6.3 (R+)
/POT0: U2.3 (POT0), U3.20 (POT0)
/POT1: U2.2 (POT1), U3.21 (POT1)
/POT2: U2.1 (POT2), U3.22 (POT2)
/REFP: C9.1, R9.2, U3.26 (REFP)
/S0: R18.1, U2.6 (S0), U3.16 (S0)
/S1: R16.2, U2.5 (S1), U3.17 (S1)
/S2: R15.1, U2.4 (S2), U3.18 (S2)
/T0: R17.1, U2.9 (T0), U3.13 (T0)
GND: C3.1, C4.2, C5.2, C8.1, C9.2, C11.1, C12.2, C15.1, C16.1, C17.1, C18.2, C19.2, C20.1, C21.1, C23.1, R15.2, R16.1, R17.2, R18.2, U1.4 (V-), U3.4 (GND), U3.7 (GND), U3.11 (GND), U3.12 (T1), U3.19 (GND), U3.24 (GND), U3.25 (REFN), U4.1 (GND), U5.1 (GND/ADJ), U6.2 (L-), U6.4 (R-), U7.1 (INDEP), U7.3 (GND), U7.7 (VSS), U7.15 (ADDR1), U7.16 (ADDR0), U8.1 (GND), U9.3 (GND), U10.2 (COM)
INL: C2.2, C7.1, U9.5 (LEFT)
INR: C6.2, C14.1, U9.6 (RIGHT)
unnamed: C1.2, R2.1
unnamed: C2.1, R4.1
unnamed: C6.1, R6.1
unnamed: C7.2, R7.1
unnamed: C10.2, R10.1
unnamed: C14.2, R13.1
unnamed: D1.1 (K), R12.1
unnamed: R11.2, R14.2, R21.1, U1.2 (-)
unnamed: R3.2, R8.2, R19.1, U1.6 (-)
unnamed: C3.2, R4.2, U3.1 (LIN)
unnamed: R1.2, U3.28 (LOUT)
unnamed: C16.2, R6.2, U3.2 (RIN)
unnamed: R5.2, U3.27 (ROUT)
unnamed: U3.10 (X1), Y1.2
unnamed: C17.2, U3.9 (X2), Y1.1
SCL: U7.13 (SCL), U9.2 (SCL)
SDA: U7.14 (SDA), U9.1 (SDA)
VGND: U1.3 (+), U1.5 (+), U7.5 (W1), U7.9 (W2), U10.1 (OUT)

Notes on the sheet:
ESR 33mΩ to 2.2Ω

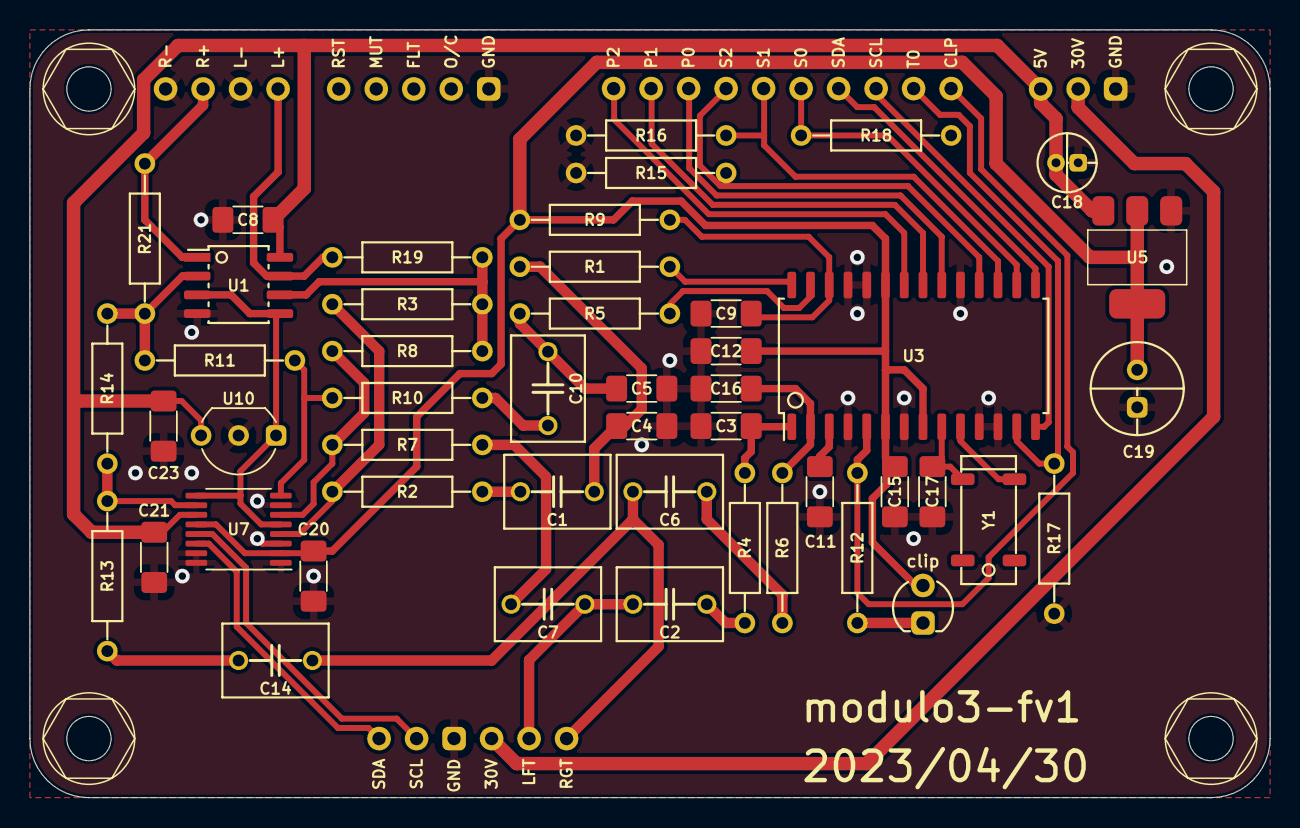
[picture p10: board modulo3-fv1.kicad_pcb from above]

Board: 2 copper layers, 84.0 x 52.0 mm, 57 parts (0 on the bottom side), 44 nets.

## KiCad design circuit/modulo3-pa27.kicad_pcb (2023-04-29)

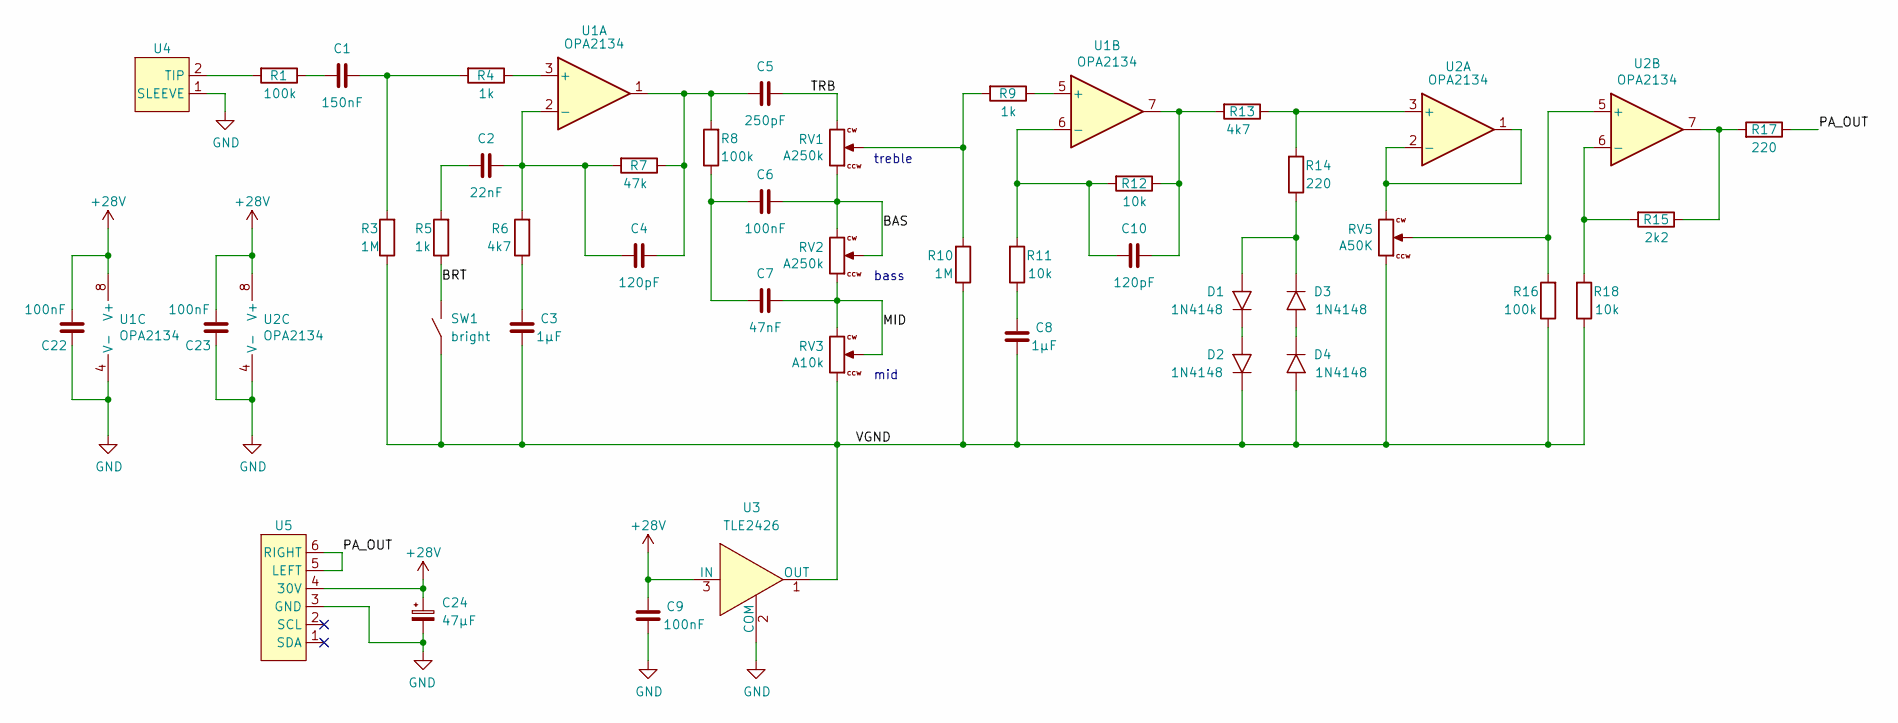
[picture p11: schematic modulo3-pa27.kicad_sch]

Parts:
C1: 150nF; C_FILM_L7.2mm_W3.5mm_P5.00mm
C2: 22nF; C_FILM_L7.2mm_W3.5mm_P5.00mm
C3, C8: 1µF; C_FILM_L7.2mm_W5.0mm_P5.00mm
C4, C10: 120pF; C_2.5MM
C5: 250pF; C_2.5MM
C6: 100nF; C_FILM_L7.2mm_W3.5mm_P5.00mm
C7: 47nF; C_FILM_L7.2mm_W3.5mm_P5.00mm
C9, C22, C23: 100nF; C_1206
C24: 47µF; CPOL_D6.3_P2.5
D1, D2, D3, D4: 1N4148; DO35
R1, R8, R16: 100k; R_10MM
R3, R10: 1M; R_10MM
R4, R5, R9: 1k; R_10MM
R6, R13: 4k7; R_10MM
R7: 47k; R_10MM
R11, R12, R18: 10k; R_10MM
R14, R17: 220; R_10MM
R15: 2k2; R_10MM
RV1, RV2: A250k; BOURNS_PTD901_xx15K
RV3: A10k; BOURNS_PTD901_xx15K
RV5: A50K; BOURNS_PTD901_xx15K
SW1: bright; JUMPER
U1, U2: OPA2134; DIP-8
U3: TLE2426; TO-92_Inline_Wide
U4: EXT_JACK
U5: PREAMP_CONN

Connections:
+28V: C9.2, C22.2, C23.2, C24.1, U1.8 (V+), U2.8 (V+), U3.3 (IN), U5.4 (30V)
/BAS: C6.2, RV1.1, RV2.2, RV2.3
/BRT: R5.1, SW1.2
/MID: C7.2, RV2.1, RV3.2, RV3.3
/PA_OUT: R17.1, U5.5 (LEFT), U5.6 (RIGHT)
/TRB: C5.2, RV1.3
/VGND: C3.1, C8.1, D2.1 (K), D4.2 (A), R3.1, R10.1, R16.1, R18.1, RV3.1, RV5.1, SW1.1, U3.1 (OUT)
GND: C9.1, C22.1, C23.1, C24.2, U1.4 (V-), U2.4 (V-), U3.2 (COM), U4.1 (SLEEVE), U5.3 (GND)
unnamed: C1.1, R1.1
unnamed: C1.2, R3.2, R4.2
unnamed: C2.1, R5.2
unnamed: C3.2, R6.1
unnamed: C4.2, C5.1, R7.1, R8.2, U1.1
unnamed: C6.1, C7.1, R8.1
unnamed: C8.2, R11.1
unnamed: C10.2, R12.1, R13.2, U1.7
unnamed: D1.2 (A), D3.1 (K), R14.1
unnamed: D1.1 (K), D2.2 (A)
unnamed: D3.2 (A), D4.1 (K)
unnamed: R9.2, R10.2, RV1.2
unnamed: R15.1, R17.2, U2.7
unnamed: R4.1, U1.3 (+)
unnamed: C2.2, C4.1, R6.2, R7.2, U1.2 (-)
unnamed: R9.1, U1.5 (+)
unnamed: C10.1, R11.2, R12.2, U1.6 (-)
unnamed: R13.1, R14.2, U2.3 (+)
unnamed: RV5.3, U2.1, U2.2 (-)
unnamed: R16.2, RV5.2, U2.5 (+)
unnamed: R15.2, R18.2, U2.6 (-)
unnamed: R1.2, U4.2 (TIP)

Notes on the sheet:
treble
bass
mid

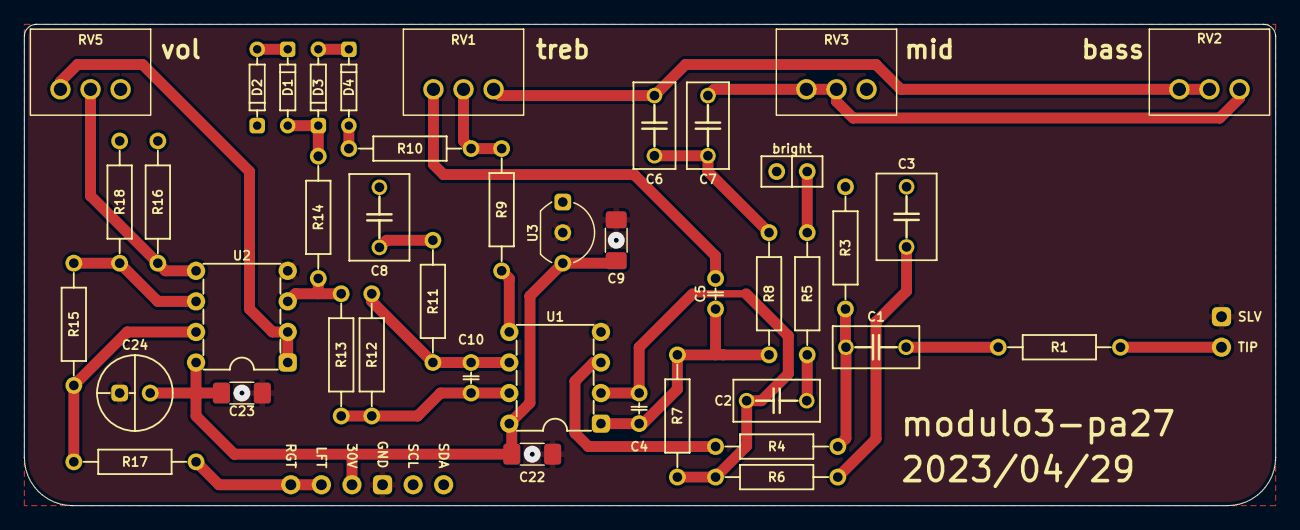
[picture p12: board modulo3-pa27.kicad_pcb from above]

Board: 2 copper layers, 104.0 x 40.0 mm, 44 parts (0 on the bottom side), 30 nets.

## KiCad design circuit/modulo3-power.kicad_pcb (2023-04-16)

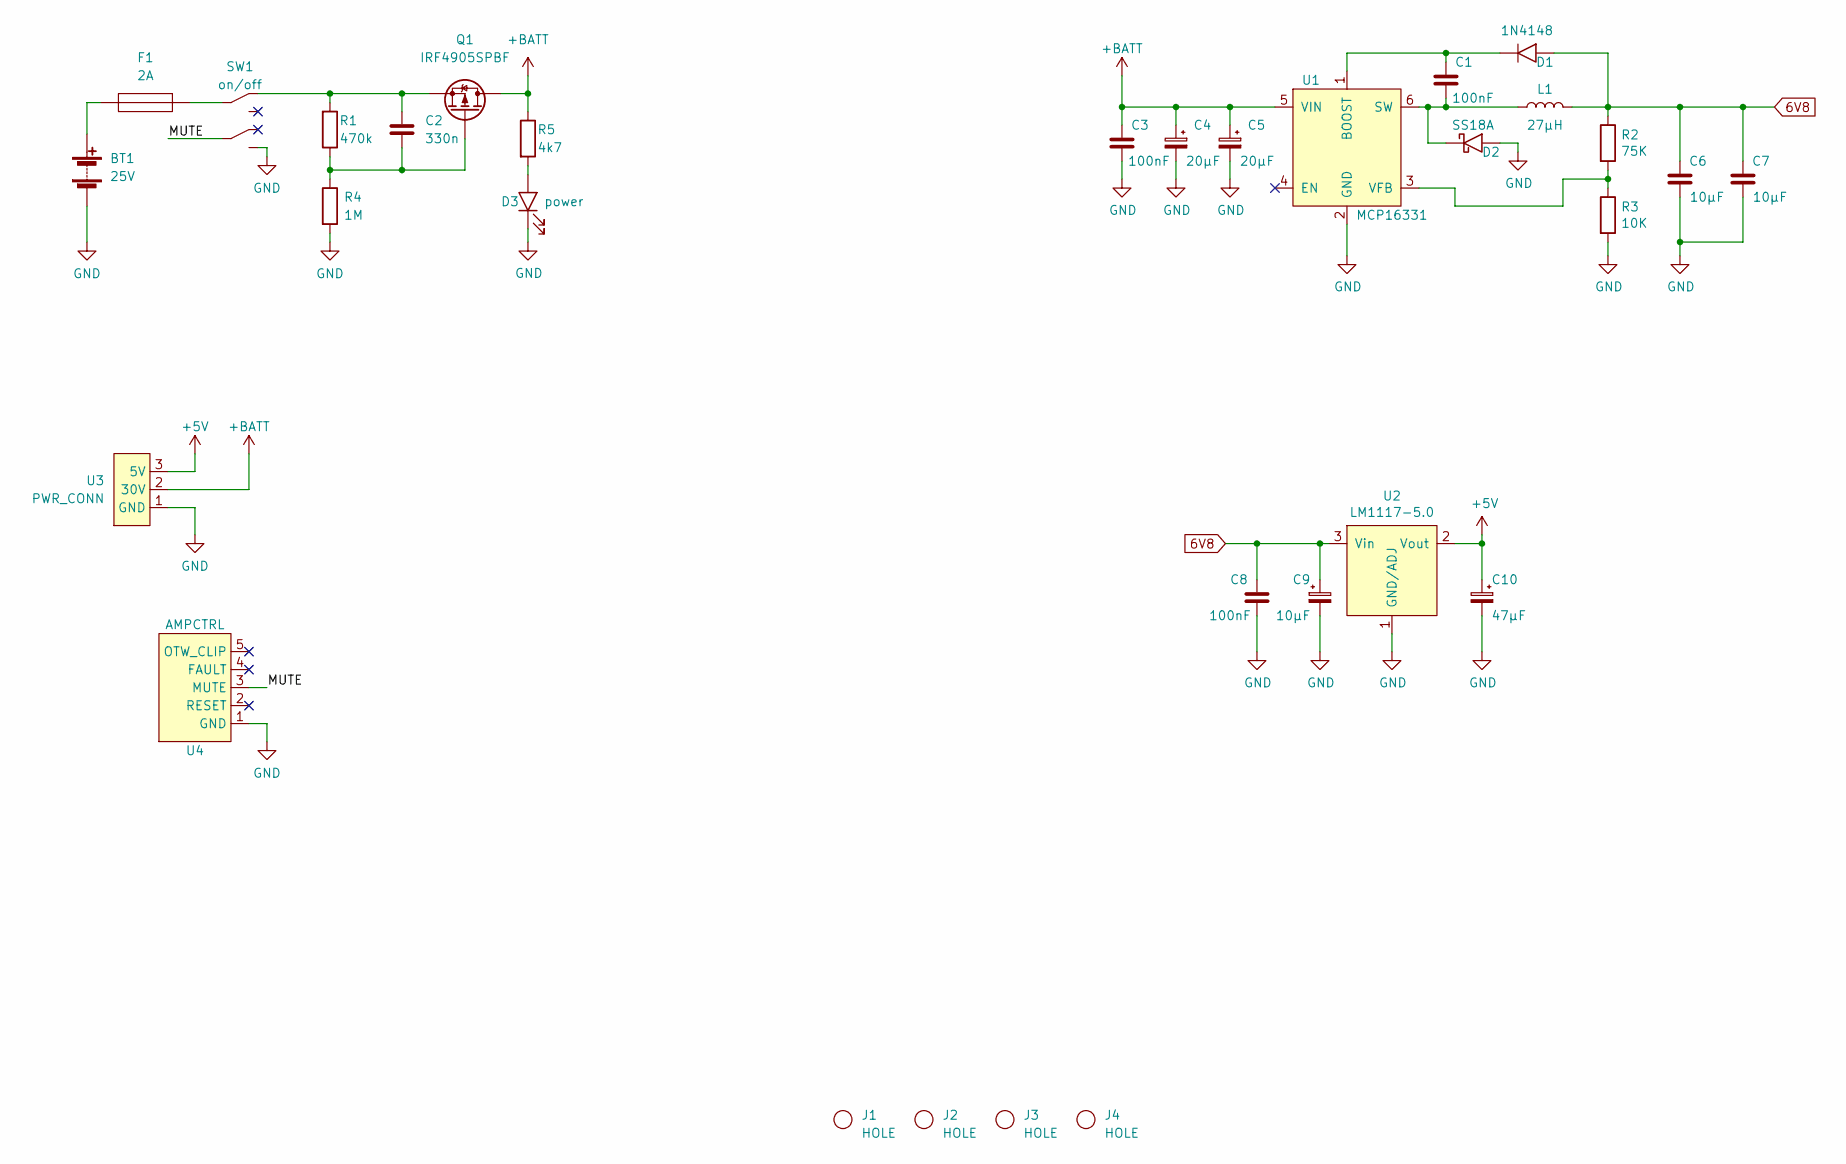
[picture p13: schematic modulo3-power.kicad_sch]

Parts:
BT1: 25V; XT60-M
C1, C3, C8: 100nF; C_1206
C2: 330n; C_5.0MM
C4, C5: 20μF; CPOL_D6.3_P2.5
C6, C7: 10μF; C_1812
C9: 10μF; CPOL_D4_P1.5
C10: 47μF; CPOL_D4_P1.5
D1: 1N4148; DO35
D2: SS18A; D_SMA
D3: power; LED_D3.0mm
F1: 2A; MF-LSMF
J1, J2, J3, J4: HOLE; MountingHole
L1: 27μH; COIL_DER0705
Q1: IRF4905SPBF; D2PAK
R1: 470k; R_10MM
R2: 75K; R_0805
R3: 10K; R_0805
R4: 1M; R_10MM
R5: 4k7; R_10MM
SW1: on/off; SW_DPDT
U1: MCP16331; SOT-23-6
U2: LM1117-5.0; TO-252-3
U3: PWR_CONN
U4: AMPCTRL

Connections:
6V8: C6.2, C7.2, C8.2, C9.1, D1.2 (A), L1.2, R2.1, U2.3 (Vin)
+5V: C10.1, U2.2 (Vout), U3.3 (5V)
+BATT: C3.2, C4.1, C5.1, Q1.2 (D), R5.1, U1.5 (VIN), U3.2 (30V)
/MUTE: SW1.5, U4.3 (MUTE)
GND: BT1.2 (-), C3.1, C4.2, C5.2, C6.1, C7.1, C8.1, C9.2, C10.2, D2.2 (A), D3.1 (K), R3.2, R4.2, SW1.6, U1.2 (GND), U2.1 (GND/ADJ), U3.1 (GND), U4.1 (GND)
unnamed: BT1.1 (+), F1.1
unnamed: C1.2, D1.1 (K), U1.1 (BOOST)
unnamed: C1.1, D2.1 (K), L1.1, U1.6 (SW)
unnamed: D3.2 (A), R5.2
unnamed: F1.2, SW1.2
unnamed: C2.2, Q1.1 (G), R1.1, R4.1
unnamed: C2.1, Q1.3 (S), R1.2, SW1.1
unnamed: R2.2, R3.1, U1.3 (VFB)

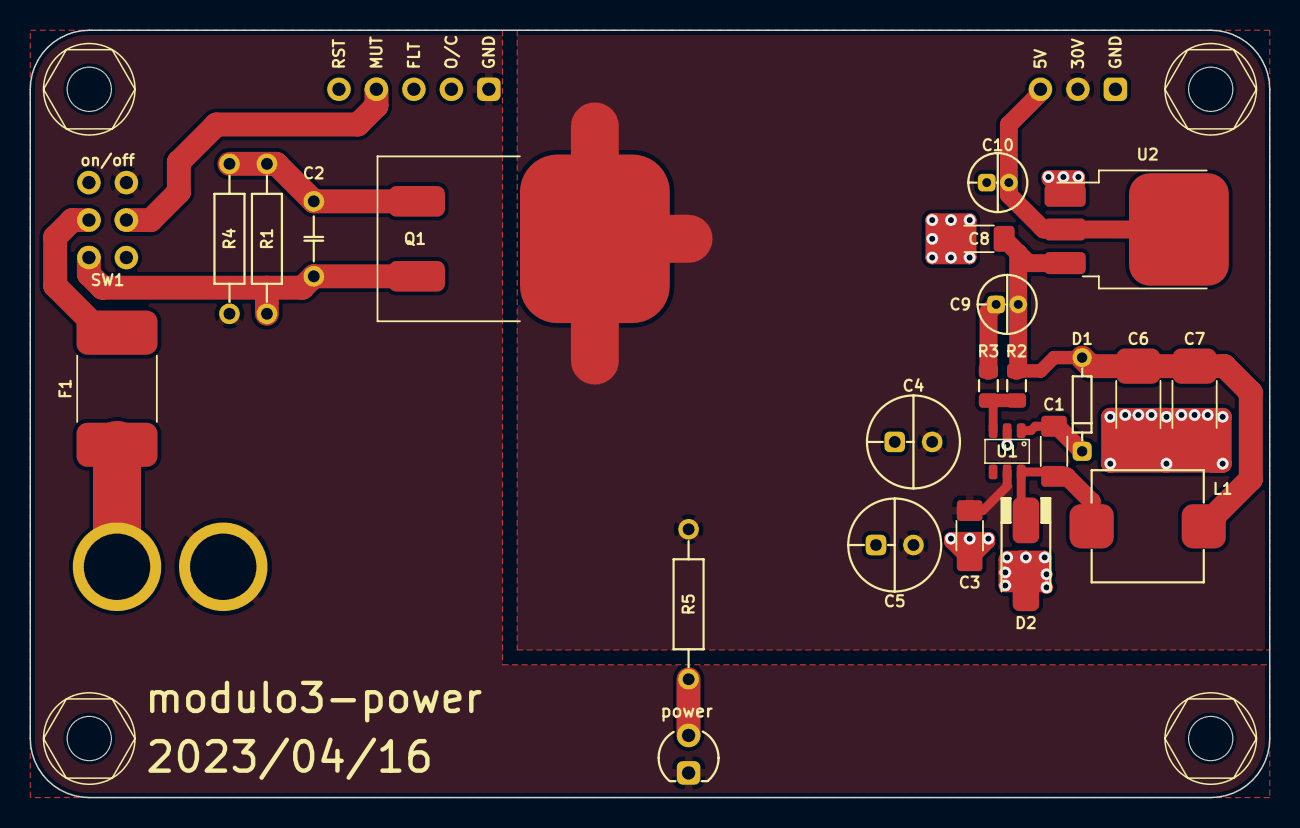
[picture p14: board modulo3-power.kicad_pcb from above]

Board: 2 copper layers, 84.0 x 52.0 mm, 31 parts (1 on the bottom side), 13 nets.

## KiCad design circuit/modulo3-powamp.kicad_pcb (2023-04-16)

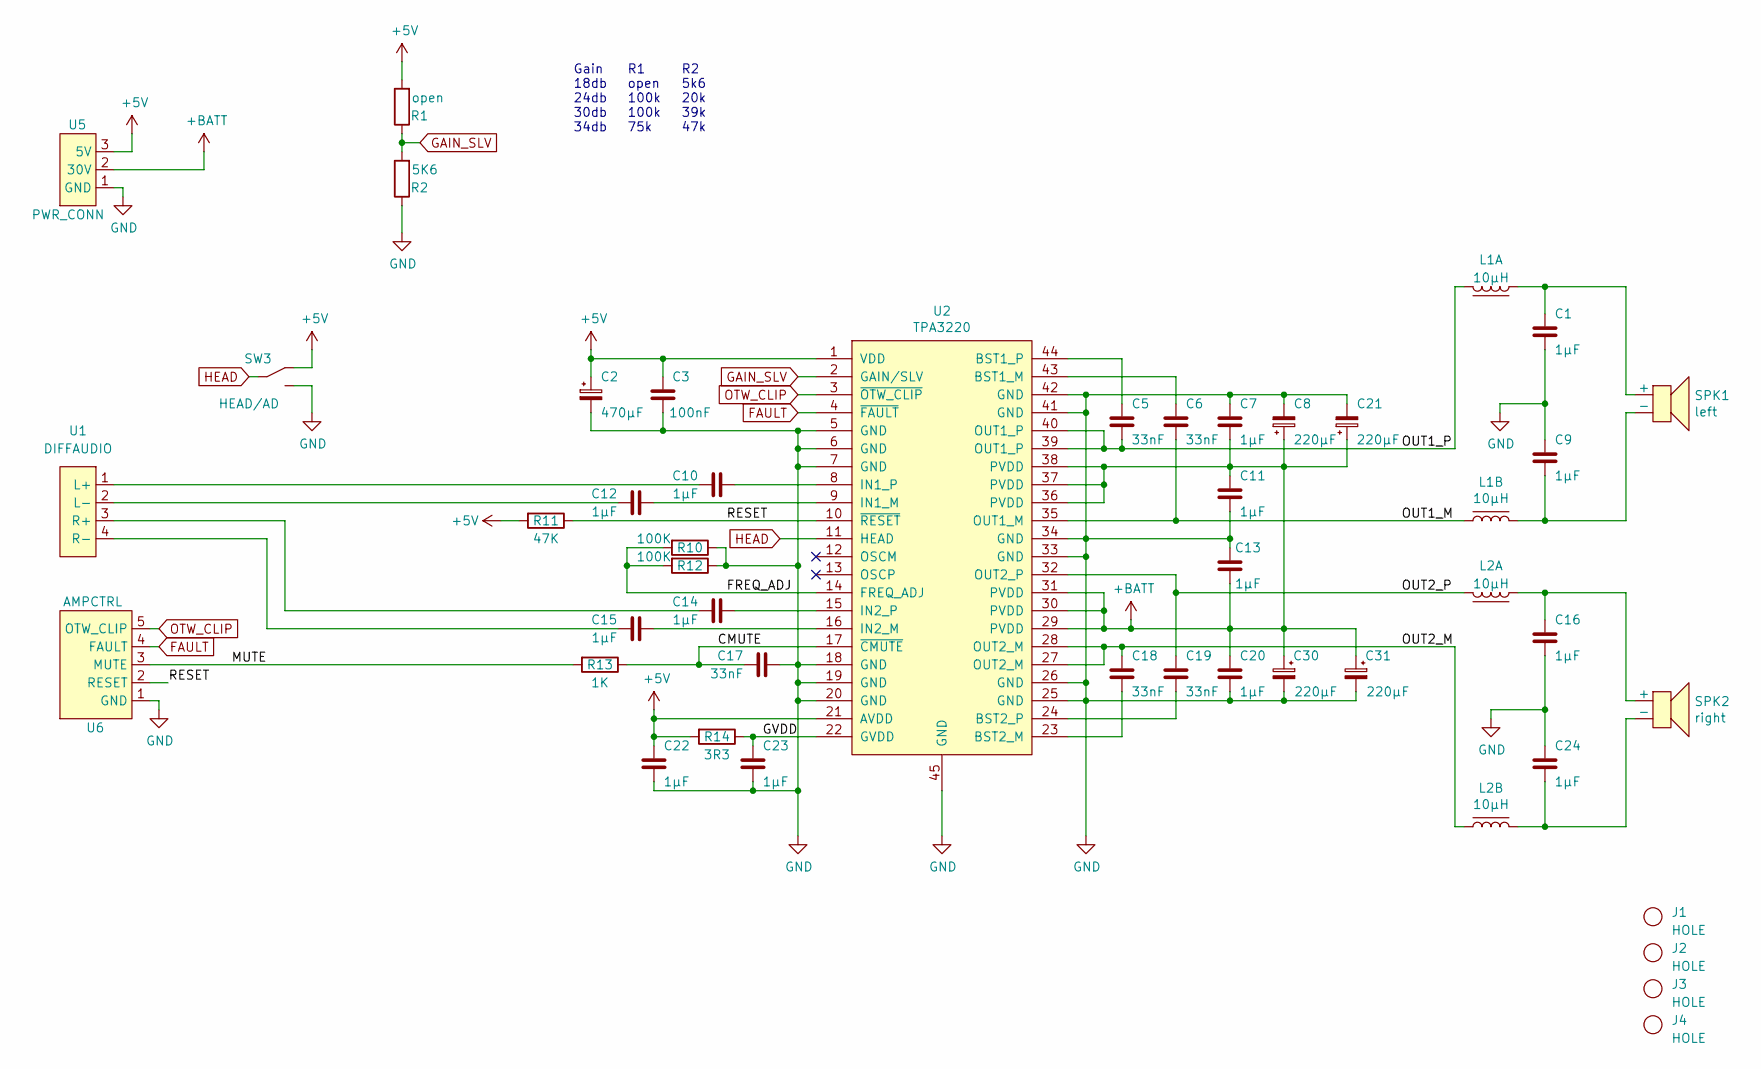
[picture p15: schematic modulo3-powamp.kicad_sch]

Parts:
C1, C9, C10, C12, C14, C15, C16, C24: 1μF; C_FILM_L7.2mm_W5.0mm_P5.00mm
C2: 470μF; CPOL_D8_P3.5
C3: 100nF; C_1206
C5, C6, C17, C18, C19: 33nF; C_1206
C7, C11, C13, C20, C22, C23: 1μF; C_1206
C8, C21, C30, C31: 220μF; CPOL_D10_P5
J1, J2, J3, J4: HOLE; MountingHole
L1, L2: 10μH; COILCRAFT-UA801x-AL
R1: open; R_10MM
R2: 5K6; R_10MM
R10, R12: 100K; R_10MM
R11: 47K; R_10MM
R13: 1K; R_10MM
R14: 3R3; R_0805
SPK1: left; SPKR_5MM_BLUE
SPK2: right; SPKR_5MM_BLUE
SW3: HEAD/AD; SW_SPDT_JUMPER
U1: DIFFAUDIO
U2: TPA3220; TSSOP-44_4.4x9.7mm_Pitch0.635mm_ThermalPad
U5: PWR_CONN
U6: AMPCTRL

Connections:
+5V: C2.1, C3.2, C22.1, R1.2, R11.2, R14.2, SW3.1, U2.1 (VDD), U2.21 (AVDD), U5.3 (5V)
+BATT: C7.2, C8.1, C11.1, C13.1, C20.1, C21.1, C30.1, C31.1, U2.29 (PVDD), U2.30 (PVDD), U2.31 (PVDD), U2.36 (PVDD), U2.37 (PVDD), U2.38 (PVDD), U5.2 (30V)
/CMUTE: C17.1, R13.1, U2.17 (~CMUTE)
/FREQ_ADJ: R10.2, R12.2, U2.14 (FREQ_ADJ)
/GVDD: C23.1, R14.1, U2.22 (GVDD)
/MUTE: R13.2, U6.3 (MUTE)
/OUT1_M: C6.2, L1.3, U2.35 (OUT1_M)
/OUT1_P: C5.2, L1.2, U2.39 (OUT1_P), U2.40 (OUT1_P)
/OUT2_M: C18.1, L2.3, U2.27 (OUT2_M), U2.28 (OUT2_M)
/OUT2_P: C19.1, L2.2, U2.32 (OUT2_P)
/RESET: R11.1, U2.10 (~RESET), U6.2 (RESET)
FAULT: U2.4 (~FAULT), U6.4 (FAULT)
GAIN_SLV: R1.1, R2.2, U2.2 (GAIN/SLV)
GND: C1.2, C2.2, C3.1, C7.1, C8.2, C9.1, C11.2, C13.2, C16.2, C17.2, C20.2, C21.2, C22.2, C23.2, C24.1, C30.2, C31.2, R2.1, R10.1, R12.1, SW3.3, U2.5 (GND), U2.6 (GND), U2.7 (GND), U2.18 (GND), U2.19 (GND), U2.20 (GND), U2.25 (GND), U2.26 (GND), U2.33 (GND), U2.34 (GND), U2.41 (GND), U2.42 (GND), U2.45 (GND), U5.1 (GND), U6.1 (GND)
HEAD: SW3.2, U2.11 (HEAD)
unnamed: C1.1, L1.1, SPK1.1 (+)
unnamed: C9.2, L1.4, SPK1.2 (-)
unnamed: C16.1, L2.1, SPK2.1 (+)
unnamed: C24.2, L2.4, SPK2.2 (-)
unnamed: C10.1, U1.1 (L+)
unnamed: C12.1, U1.2 (L-)
unnamed: C14.1, U1.3 (R+)
unnamed: C15.1, U1.4 (R-)
unnamed: C6.1, U2.43 (BST1_M)
unnamed: C5.1, U2.44 (BST1_P)
unnamed: C18.2, U2.23 (BST2_M)
unnamed: C19.2, U2.24 (BST2_P)
unnamed: C12.2, U2.9 (IN1_M)
unnamed: C10.2, U2.8 (IN1_P)
unnamed: C15.2, U2.16 (IN2_M)
unnamed: C14.2, U2.15 (IN2_P)
OTW_CLIP: U2.3 (~OTW_CLIP), U6.5 (OTW_CLIP)

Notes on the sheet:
Gain 18db 24db 30db 34db
R2 5k6 20k 39k 47k
R1 open 100k 100k 75k

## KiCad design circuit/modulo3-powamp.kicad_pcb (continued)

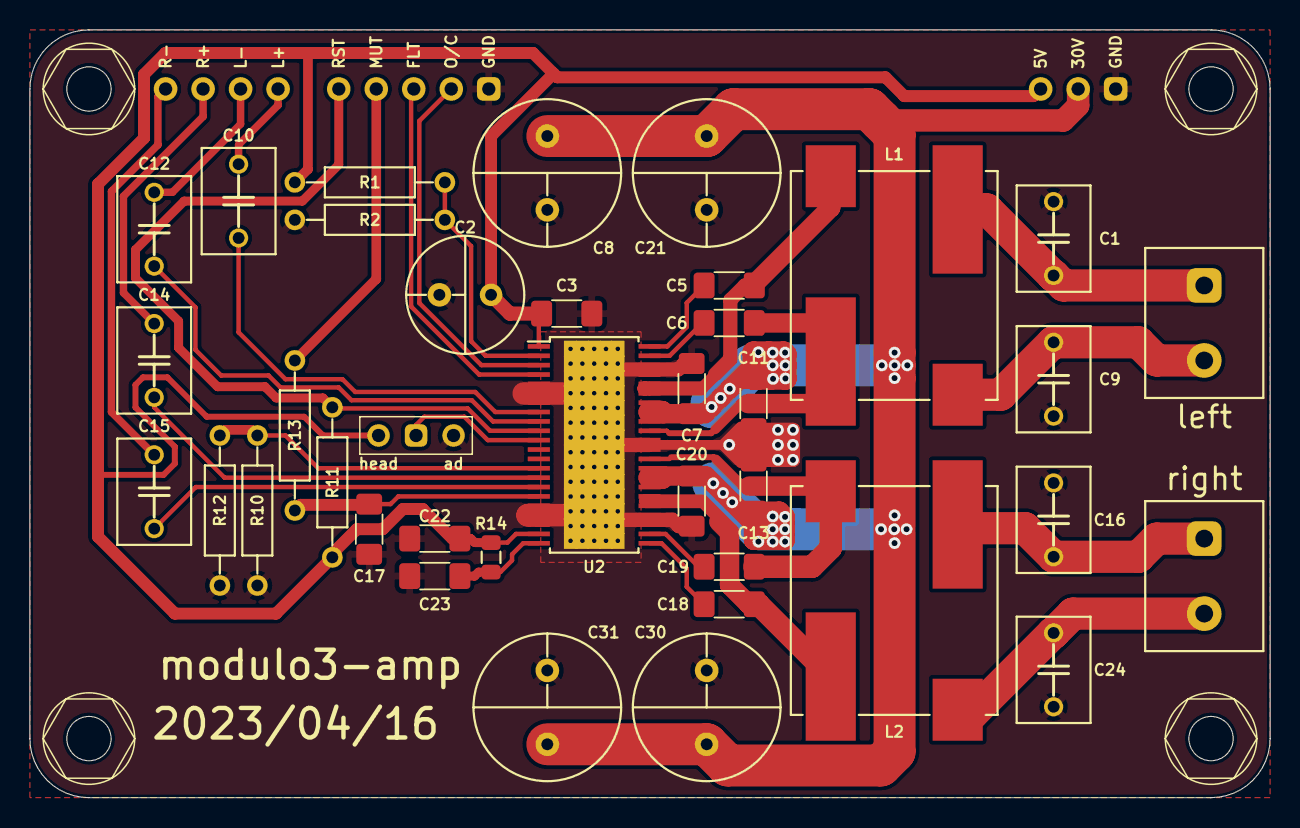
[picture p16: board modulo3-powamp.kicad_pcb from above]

Board: 2 copper layers, 84.0 x 52.0 mm, 45 parts (0 on the bottom side), 32 nets.

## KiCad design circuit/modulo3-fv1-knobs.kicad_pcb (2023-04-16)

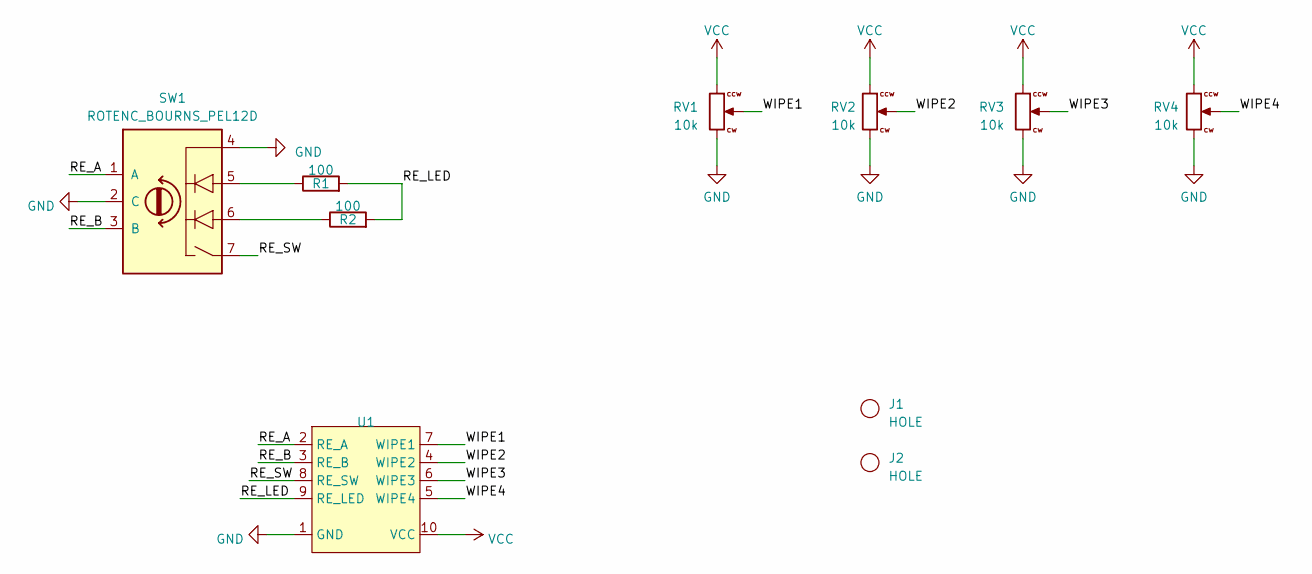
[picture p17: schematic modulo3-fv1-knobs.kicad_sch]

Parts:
J1, J2: HOLE; MountingHole
R1, R2: 100; R_10MM
RV1, RV2, RV3, RV4: 10k; BOURNS_PTD901_xx15K
SW1: ROTENC_BOURNS_PEL12D; BOURNS_PEL12D-2xxx
U1: KNOBS

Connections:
/RE_A: SW1.1 (A), U1.2 (RE_A)
/RE_B: SW1.3 (B), U1.3 (RE_B)
/RE_LED: R1.2, R2.2, U1.9 (RE_LED)
/RE_SW: SW1.7, U1.8 (RE_SW)
/WIPE1: RV1.2, U1.7 (WIPE1)
/WIPE2: RV2.2, U1.4 (WIPE2)
/WIPE3: RV3.2, U1.6 (WIPE3)
/WIPE4: RV4.2, U1.5 (WIPE4)
GND: RV1.3, RV2.3, RV3.3, RV4.3, SW1.2 (C), SW1.4, U1.1 (GND)
unnamed: R1.1, SW1.5
unnamed: R2.1, SW1.6
VCC: RV1.1, RV2.1, RV3.1, RV4.1, U1.10 (VCC)



Board: 2 copper layers, 85.0 x 23.0 mm, 10 parts (2 on the bottom side), 12 nets.

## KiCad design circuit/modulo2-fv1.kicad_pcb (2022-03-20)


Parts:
C1, C2, C7, C10, C14: 1µF; C_FILM_L7.2mm_W5.0mm_P5.00mm
C3, C6: 1nF; C_1206
C4, C5: 10nF; C_1206
C8, C12, C15, C16: 100nF; C_1206
C9, C11: 1µF; C_1206
C13: 10µF; CPOL_D6.3_P2.5
C17, C20: 22p; C_5MM_1206
C18: 10µF; CPOL_D4_P1.5
C19: 100µF; CPOL_D6.3_P2.5
C23: 100nF; C_5MM_1206
D1: clip; LED_D3.0mm_Horizontal_Short
D2: 1; LED_D3.0mm_Horizontal_Long
D3: 2; LED_D3.0mm_Horizontal_Long
D4: 3; LED_D3.0mm_Horizontal_Long
D5: 4; LED_D3.0mm_Horizontal_Short
D6: 5; LED_D3.0mm_Horizontal_Short
D7: 6; LED_D3.0mm_Horizontal_Short
J1: CONN_01X04; PIN_1x04
J3: CONN_01X02; PIN_1x02
J4, J5: HOLE; MountingHole
J6: USB_OTG; USB_OTG_THT
R1, R5: 1K; R_1206
R2, R3, R7, R8, R10, R11, R13, R14: 10K; R_1206
R4, R25: 1K; R_10MM
R6: 1K5; R_10MM
R9, R12, R28: 100; R_10MM
R15, R16, R17, R18, R19, R20, R24, R26, R27: 10K; R_10MM
R21, R22: 68; R_10MM
R23: 1M; R_10MM
RN1, RN2: 100; R_Array_x4_1206
RV1: B10K; BOURNS_PTD902_xx15K
RV2, RV3, RV4: 50K; BOURNS_PTD901_xx15K
RV5: A50K; BOURNS_PTD902_xx15K
SW1: ROTENC_BOURNS_PEL12D; BOURNS_PEL12D-2xxx
SW2: USB_POW; PIN_1x02
T1: B0; TestPin
T2: ADC6; TestPin
U1: NE5532; SOIC-8_3.9x4.9mm_P1.27mm
U2: PWR_CONN
U3: FV-1; SOIC-28_7.5x17.9mm_Pitch1.27mm
U4: AVR-ISP6; AVR_ISP6
U5: LM1117 3V3; SOT-223
U6: ATmega328p; TQFP-32_7x7mm_Pitch0.8mm
U7: DBG_UART
U8: 74164; SOIC-14_3.9x8.7mm_P1.27mm
U9: AMPCTRL; PIN_1x03
U10: TLE2426; TO-92_Inline_Wide
Y1: 12MHz; Crystal_HC49-U_Vertical

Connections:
+3V3: C12.1, C15.2, C16.2, C19.1, D1.2 (A), R9.1, R19.2, R23.2, R27.1, RV2.3, RV3.3, RV4.3, U3.6 (AVDD), U3.8 (DVDD), U3.23 (DVDD), U4.2 (VCC), U5.2 (Vout), U6.4 (VCC), U6.6 (VCC), U6.18 (AVCC), U6.20 (AREF), U8.14 (VCC)
+5V: C18.1, SW2.2, U2.3 (5V), U5.3 (Vin)
+24V: C8.2, C13.1, C23.2, R24.1, U1.8 (V+), U2.2 (30V), U10.3 (IN)
/AVR_RST: R19.1, U4.5 (RST), U6.29 (PC6(~RESET))
/D+: R21.2, U6.32 ((INT0)PD2)
/D-: R22.2, U6.1 ((INT1)PD3)
/DBG_TX: U6.31 ((TXD)PD1), U7.2 (TX)
/FVL: C1.1, C4.1, R1.1
/FVR: C5.1, C10.1, R5.1
/FV_CLK: R20.2, U6.14 ((~SS/OC1B)PB2)
/IN_V: C6.2, R24.2, R25.1, U6.22 (ADC7)
/LED_RST: U6.13 ((OC1A)PB1), U8.9 (~R)
/MID: C11.2, U3.3 (MID)
/MISO: U4.1 (MISO), U6.16 ((MISO)PB4)
/MOSI: U4.4 (MOSI), U6.15 ((MOSI/OC2)PB3), U8.1 (A), U8.2 (B)
/OUTL: J1.2, RV5.2, RV5.3, U1.7
/OUTR: J1.4, RV5.5 (2), RV5.6 (3), U1.1
/POW_MUTE: R27.2, U6.2 ((XCK/T0)PD4), U9.3 (MUTE)
/POW_RST: R28.2, U6.30 ((RXD)PD0)
/REFP: C9.1, R9.2, U3.26 (REFP)
/ROT_A: SW1.1 (A), U6.10 ((AIN0)PD6)
/ROT_B: SW1.3 (B), U6.9 ((T1)PD5)
/ROT_SW: SW1.7, U6.11 ((AIN1)PD7)
/S0: R18.1, U3.16 (S0), U6.26 ((ADC3)PC3)
/S1: R16.2, U3.17 (S1), U6.25 ((ADC2)PC2)
/S2: R15.1, U3.18 (S2), U6.24 ((ADC1)PC1)
/SCK: U4.3 (SCK), U6.17 ((SCK)PB5), U8.8 (CK)
/SCL: U3.14 (SCL), U6.28 ((ADC5/SCL)PC5)
/SDA: U3.15 (SDA), U6.27 ((ADC4/SDA)PC4)
/T0: R17.1, U3.13 (T0), U6.23 ((ADC0)PC0)
BL_ROTENC: RN1.6 (R3.2), SW1.5
GND: C3.1, C4.2, C5.2, C6.1, C8.1, C9.2, C11.1, C12.2, C13.2, C15.1, C16.1, C17.2, C18.2, C19.2, C20.2, C23.1, D2.1 (K), D3.1 (K), D4.1 (K), D5.1 (K), D6.1 (K), D7.1 (K), J1.1, J1.3, J3.1, J6.5 (GND), R6.2, R15.2, R16.1, R17.2, R18.2, R25.2, R26.2, RV2.1, RV3.1, RV4.1, SW1.2 (C), SW1.4, U1.4 (V-), U2.1 (GND), U3.4 (GND), U3.7 (GND), U3.11 (GND), U3.12 (T1), U3.19 (GND), U3.24 (GND), U3.25 (REFN), U4.6 (GND), U5.1 (GND/ADJ), U6.3 (GND), U6.5 (GND), U6.21 (AGND), U7.1 (GND), U8.7 (GND), U9.1 (GND), U10.2 (COM)
GR_ROTENC: RN1.5 (R4.2), SW1.6
IN: C2.2, C7.1, C14.1, J3.2
unnamed: C1.2, R2.1
unnamed: C2.1, R4.1
unnamed: C3.2, R4.2, U3.1 (LIN), U3.2 (RIN)
unnamed: C7.2, R7.1
unnamed: C10.2, R10.1
unnamed: C14.2, R13.1
unnamed: C17.1, U6.7 (PB6(XTAL1/TOSC1)), Y1.1
unnamed: C20.1, U6.8 (PB7(XTAL2/TOSC2)), Y1.2
unnamed: D1.1 (K), R12.1
unnamed: D2.2 (A), RN1.7 (R2.2)
unnamed: D3.2 (A), RN2.1 (R1.1)
unnamed: D4.2 (A), RN2.3 (R3.1)
unnamed: D5.2 (A), RN1.8 (R1.2)
unnamed: D6.2 (A), RN2.2 (R2.1)
unnamed: D7.2 (A), RN2.4 (R4.1)
unnamed: J6.1 (VBUS), SW2.1
unnamed: J6.2 (D-), R22.1, R23.1
unnamed: J6.3 (D+), R6.1, R21.1
unnamed: R1.2, U3.28 (LOUT)
unnamed: R2.2, R3.1, RV1.4 (1)
unnamed: R3.2, R8.2, RV5.1, U1.6 (-)
unnamed: R5.2, U3.27 (ROUT)
unnamed: R7.2, R8.1, RV1.6 (3)
unnamed: R10.2, R11.1, RV1.1
unnamed: R11.2, R14.2, RV5.4 (1), U1.2 (-)
unnamed: R12.2, U3.5 (CLIP)
unnamed: R13.2, R14.1, RV1.3
unnamed: R20.1, U3.10 (X1)
unnamed: R26.1, R28.1, U9.2 (RESET)
unnamed: RN1.1 (R1.1), U8.6 (Qd)
unnamed: RN1.2 (R2.1), U8.5 (Qc)
unnamed: RN1.3 (R3.1), U8.4 (Qb)
unnamed: RN1.4 (R4.1), U8.3 (Qa)
unnamed: RN2.5 (R4.2), U8.13 (Qh)
unnamed: RN2.6 (R3.2), U8.12 (Qg)
unnamed: RN2.7 (R2.2), U8.11 (Qf)
unnamed: RN2.8 (R1.2), U8.10 (Qe)
unnamed: RV2.2, U3.22 (POT2)
unnamed: RV3.2, U3.21 (POT1)
unnamed: RV4.2, U3.20 (POT0)
unnamed: T1.1, U6.12 ((ICP)PB0)
unnamed: T2.1, U6.19 (ADC6)
VGND: RV1.2, RV1.5 (2), U1.3 (+), U1.5 (+), U10.1 (OUT)

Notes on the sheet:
ESR 33mΩ to 2.2Ω



Board: 2 copper layers, 105.0 x 47.0 mm, 83 parts (8 on the bottom side), 77 nets.

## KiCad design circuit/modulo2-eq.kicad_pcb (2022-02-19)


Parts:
C1, C3: 1μF; C_FILM_L7.2mm_W5.0mm_P5.00mm
C4: 680nF; C_FILM_L7.2mm_W4.5mm_P5.00mm
C5: 22nF; C_5MM_1206
C6: 470nF; C_FILM_L7.2mm_W4.5mm_P5.00mm
C7: 10nF; C_5MM_1206
C8, C10: 220nF; C_FILM_L7.2mm_W3.5mm_P5.00mm
C9: 5.6nF; C_5MM_1206
C11: 2.7nF; C_5MM_1206
C12: 100nF; C_FILM_L7.2mm_W3.5mm_P5.00mm
C13: 1.5nF; C_5MM_1206
C14: 47nF; C_5MM_1206
C15: 680pF; C_5MM_1206
C16, C17, C19, C20: 100nF; C_1206
C18: 100nF; C_FILM_L7.2mm_W2.5mm_P5.00mm
C21: 330nF; C_FILM_L7.2mm_W4.5mm_P5.00mm
C22: 220nF; C_FILM_L7.2mm_W4.5mm_P5.00mm
D1, D2: 1N4733a; DO41
J1: JACK_MONO; JACK_CL13106
J2, J3: HOLE; MountingHole
J4: CONN_01X04; PIN_1x04
J5: CONN_01X02; PIN_1x02
Q1: MMBFJ201; SOT-23_with_jig
R1, R5, R14, R15, R16, R20, R21, R22: 100k; R_10MM
R2, R6: 3k3; R_10MM
R3: 15K; R_10MM
R4, R8, R10: 1M; R_10MM
R9: 1K5; R_10MM
R11, R12, R13, R17, R18, R19: 470; R_10MM
RV1, RV2, RV3, RV4, RV5, RV6: 10k; BOURNS_PTD901_xx15K
U1, U2, U3, U4: NE5532; SOIC-8_3.9x4.9mm_P1.27mm
U5: TLE2426; TO-92_Inline_Wide
U6: PWR_CONN

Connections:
+BATT: C16.2, C17.2, C18.2, C19.2, C20.2, R3.2, R4.2, U1.8 (V+), U2.8 (V+), U3.8 (V+), U4.8 (V+), U5.3 (IN), U6.2 (30V)
/OUT: J4.2, J4.4, J5.2, R2.1, U1.7
/jfet_d: C1.2, Q1.1 (D), R3.1, R4.1
/jfet_g: D1.2 (A), J1.6 (TIP), Q1.3 (G), R8.1
/jfet_s: Q1.2 (S), R9.1, R10.1
BOOST: R2.2, RV1.3, RV2.3, RV3.3, RV4.3, RV5.3, RV6.3, U1.6 (-)
CUT: R6.1, RV1.1, RV2.1, RV3.1, RV4.1, RV5.1, RV6.1, U1.5 (+)
GND: C16.1, C17.1, C18.1, C19.1, C20.1, D2.2 (A), J1.1, J1.3, J1.4 (SLEEVE), J4.1, J4.3, J5.1, R8.2, R9.2, R10.2, U1.4 (V-), U2.4 (V-), U3.4 (V-), U4.4 (V-), U5.2 (COM), U6.1 (GND)
unnamed: C1.1, R5.2
unnamed: C3.1, C4.1, C5.2, R11.1
unnamed: C3.2, C4.2, RV1.2
unnamed: C5.1, R14.2, U2.5 (+)
unnamed: C7.1, R15.2, U2.3 (+)
unnamed: C9.1, R16.2, U3.5 (+)
unnamed: C10.1, C11.2, R17.1
unnamed: C10.2, RV4.2
unnamed: C11.1, R20.2, U3.3 (+)
unnamed: C12.1, C13.2, R18.1
unnamed: C12.2, RV5.2
unnamed: C13.1, R21.2, U4.5 (+)
unnamed: C14.1, C15.2, R19.1
unnamed: C14.2, RV6.2
unnamed: C15.1, R22.2, U4.3 (+)
unnamed: C6.1, C7.2, C21.1, R12.1
unnamed: C6.2, C21.2, RV2.2
unnamed: C8.1, C9.2, C22.1, R13.1
unnamed: C8.2, C22.2, RV3.2
unnamed: D1.1 (K), D2.1 (K)
unnamed: R1.1, R6.2, U1.1
unnamed: R1.2, R5.1, U1.2 (-)
unnamed: R11.2, U2.6 (-), U2.7
unnamed: R12.2, U2.1, U2.2 (-)
unnamed: R13.2, U3.6 (-), U3.7
unnamed: R17.2, U3.1, U3.2 (-)
unnamed: R18.2, U4.6 (-), U4.7
unnamed: R19.2, U4.1, U4.2 (-)
VGND: R14.1, R15.1, R16.1, R20.1, R21.1, R22.1, U1.3 (+), U5.1 (OUT)

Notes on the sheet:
100nF 1.4nF
200nF 2.7nF
4KHz
1.6μF 22nF
250Hz
50nF 680pF
800nF 11nF
400nF 5.6nF
1KHz
500Hz
2KHz
125Hz



Board: 2 copper layers, 105.0 x 47.0 mm, 62 parts (3 on the bottom side), 37 nets.

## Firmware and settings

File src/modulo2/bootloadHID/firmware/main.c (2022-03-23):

/* Name: main.c
 * Project: AVR bootloader HID
 * Author: Christian Starkjohann
 * Creation Date: 2007-03-19
 * Tabsize: 4
 * Copyright: (c) 2007 by OBJECTIVE DEVELOPMENT Software GmbH
 * License: GNU GPL v2 (see License.txt)
 * This Revision: $Id$
 */

#include <avr/io.h>
#include <avr/interrupt.h>
#include <avr/pgmspace.h>
#include <avr/wdt.h>
#include <avr/boot.h>
#include <string.h>
#include <util/delay.h>

static void leaveBootloader() __attribute__((__noreturn__));

#include "bootloaderconfig.h"
#include "usbdrv.c"

/* ------------------------------------------------------------------------ */

#ifndef ulong
#   define ulong    unsigned long
#endif
#ifndef uint
#   define uint     unsigned int
#endif

#if (FLASHEND) > 0xffff /* we need long addressing */
#   define addr_t           ulong
#else
#   define addr_t           uint
#endif

static addr_t           currentAddress; /* in bytes */
static uchar            offset;         /* data already processed in current transfer */
#if BOOTLOADER_CAN_EXIT
static uchar            exitMainloop;
#endif


const PROGMEM char usbHidReportDescriptor[33] = {
    0x06, 0x00, 0xff,              // USAGE_PAGE (Generic Desktop)
    0x09, 0x01,                    // USAGE (Vendor Usage 1)
    0xa1, 0x01,                    // COLLECTION (Application)
    0x15, 0x00,                    //   LOGICAL_MINIMUM (0)
    0x26, 0xff, 0x00,              //   LOGICAL_MAXIMUM (255)
    0x75, 0x08,                    //   REPORT_SIZE (8)

    0x85, 0x01,                    //   REPORT_ID (1)
    0x95, 0x06,                    //   REPORT_COUNT (6)
    0x09, 0x00,                    //   USAGE (Undefined)
    0xb2, 0x02, 0x01,              //   FEATURE (Data,Var,Abs,Buf)

    0x85, 0x02,                    //   REPORT_ID (2)
    0x95, 0x83,                    //   REPORT_COUNT (131)
    0x09, 0x00,                    //   USAGE (Undefined)
    0xb2, 0x02, 0x01,              //   FEATURE (Data,Var,Abs,Buf)
    0xc0                           // END_COLLECTION
};

/* allow compatibility with avrusbboot's bootloaderconfig.h: */
#ifdef BOOTLOADER_INIT
#   define bootLoaderInit()         BOOTLOADER_INIT
#endif
#ifdef BOOTLOADER_CONDITION
#   define bootLoaderCondition()    BOOTLOADER_CONDITION
#endif

/* compatibility with ATMega88 and other new devices: */
#ifndef TCCR0
#define TCCR0   TCCR0B
#endif
#ifndef GICR
#define GICR    MCUCR
#endif

static void (*nullVector)(void) __attribute__((__noreturn__));

static void leaveBootloader()
{
    DBG1(0x01, 0, 0);
    cli();
    boot_rww_enable();
    USB_INTR_ENABLE = 0;
    USB_INTR_CFG = 0;       /* also reset config bits */
#if F_CPU == 12800000
    TCCR0 = 0;              /* default value */
#endif
    GICR = (1 << IVCE);     /* enable change of interrupt vectors */
    GICR = (0 << IVSEL);    /* move interrupts to application flash section */
/* We must go through a global function pointer variable instead of writing
 *  ((void (*)(void))0)();
 * because the compiler optimizes a constant 0 to "rcall 0" which is not
 * handled correctly by the assembler.
 */
    nullVector();
}

uchar   usbFunctionSetup(uchar data[8])
{
usbRequest_t    *rq = (void *)data;
static uchar    replyBuffer[7] = {
        1,                              /* report ID */
        SPM_PAGESIZE & 0xff,
        SPM_PAGESIZE >> 8,
        ((long)FLASHEND + 1) & 0xff,
        (((long)FLASHEND + 1) >> 8) & 0xff,
        (((long)FLASHEND + 1) >> 16) & 0xff,
        (((long)FLASHEND + 1) >> 24) & 0xff
    };

    if(rq->bRequest == USBRQ_HID_SET_REPORT){
        if(rq->wValue.bytes[0] == 2){
            offset = 0;
            return USB_NO_MSG;
        }
#if BOOTLOADER_CAN_EXIT
        else{
            exitMainloop = 1;
        }
#endif
    }else if(rq->bRequest == USBRQ_HID_GET_REPORT){
        usbMsgPtr = (usbMsgPtr_t)replyBuffer;
        return 7;
    }
    return 0;
}

uchar usbFunctionWrite(uchar *data, uchar len)
{
union {
    addr_t  l;
    uint    s[sizeof(addr_t)/2];
    uchar   c[sizeof(addr_t)];
}       address;
uchar   isLast;

    address.l = currentAddress;
    if(offset == 0){
        DBG1(0x30, data, 3);
        address.c[0] = data[1];
        address.c[1] = data[2];
#if (FLASHEND) > 0xffff /* we need long addressing */
        address.c[2] = data[3];
        address.c[3] = 0;
#endif
        data += 4;
        len -= 4;
    }
    DBG1(0x31, (void *)&currentAddress, 4);
    offset += len;
    isLast = offset & 0x80; /* != 0 if last block received */
    do{
        addr_t prevAddr;
#if SPM_PAGESIZE > 256
        uint pageAddr;
#else
        uchar pageAddr;
#endif
        DBG1(0x32, 0, 0);
        pageAddr = address.s[0] & (SPM_PAGESIZE - 1);
        if(pageAddr == 0){              /* if page start: erase */
            DBG1(0x33, 0, 0);
#ifndef TEST_MODE
            cli();
            boot_page_erase(address.l); /* erase page */
            sei();
            boot_spm_busy_wait();       /* wait until page is erased */
#endif
        }
        cli();
        boot_page_fill(address.l, *(short *)data);
        sei();
        prevAddr = address.l;
        address.l += 2;
        data += 2;
        /* write page when we cross page boundary */
        pageAddr = address.s[0] & (SPM_PAGESIZE - 1);
        if(pageAddr == 0){
            DBG1(0x34, 0, 0);
#ifndef TEST_MODE
            cli();
            boot_page_write(prevAddr);
            sei();
            boot_spm_busy_wait();
#endif
        }
        len -= 2;
    }while(len);
    currentAddress = address.l;
    DBG1(0x35, (void *)&currentAddress, 4);
    return isLast;
}

static void initForUsbConnectivity(void)
{
uchar   i = 0;

#if F_CPU == 12800000
    TCCR0 = 3;          /* 1/64 prescaler */
#endif
    usbInit();
    /* enforce USB re-enumerate: */
    usbDeviceDisconnect();  /* do this while interrupts are disabled */
    do{             /* fake USB disconnect for > 250 ms */
        wdt_reset();
        _delay_ms(1);
    }while(--i);
    usbDeviceConnect();
    sei();
}

// just a dummy function to suppress GCC warning
USB_PUBLIC usbMsgLen_t usbFunctionDescriptor(struct usbRequest *rq)
{
	return 0;
}

#define FV_FREQ_DEFAULT			32768
#define FV_FREQ_TO_CNT(freq)	(uint16_t)(((F_CPU/2)/(freq))-1)

#define FV_CLK_PORT		B
#define FV_CLK_BIT		2

#define LED_DATA_PORT	B
#define LED_DATA_BIT	3

#define LED_CLOCK_PORT	B
#define LED_CLOCK_BIT	5

#define LED_RST_PORT	B
#define LED_RST_BIT		1

int /*__attribute__((noreturn))*/ main(void)
{
    /* initialize hardware */
    bootLoaderInit();

	// turn on the light-show by setting up the
	// SPI to communicate with the external shift register
	DDRB |= (_BV(FV_CLK_BIT) | _BV(LED_DATA_BIT) | _BV(LED_CLOCK_BIT) | _BV(LED_RST_BIT));
	PORTB |= _BV(LED_RST_BIT);
	
	SPCR = _BV(SPE) | _BV(MSTR);
	
	// setup the local timer
	TCCR0A = 0x00;
	TCCR0B = _BV(CS02) | _BV(CS00);		// 1024 prescler
	
	// keep FV-1 one happy by giving it a 32KHz clock
	// otherwise it will turn on the clip LED
	TCCR1A = _BV(COM1B0);	// output clock on B2
	TCCR1B = _BV(WGM12) |	// CTC
			 _BV(CS10);		// prescaler 1

	OCR1A = FV_FREQ_TO_CNT(FV_FREQ_DEFAULT);

    odDebugInit();
    DBG1(0x00, 0, 0);
    // wait for system to send new the firmware update
	// until the rotenc button is pressed
    if (bootLoaderCondition())
	{
        uchar i = 0, j = 0;
#ifndef TEST_MODE
        GICR = (1 << IVCE);  /* enable change of interrupt vectors */
        GICR = (1 << IVSEL); /* move interrupts to boot flash section */
#endif
        initForUsbConnectivity();

		uint8_t ovcnt = 1;
		uint8_t pattern = 0;
        do{ /* main event loop */
            wdt_reset();
            usbPoll();
			
			// light-show
			if (TIFR0 & _BV(TOV0))
			{
				++ovcnt;
				if ((ovcnt & 0b111) == 0)
				{
					if (pattern == 0b10101010)
						pattern = 0b01010101;
					else
						pattern = 0b10101010;
					
					SPDR = pattern;
				}
				
				// clear TOV0
				TIFR0 |= _BV(TOV0);
			}
			
#if BOOTLOADER_CAN_EXIT
            if(exitMainloop){
#if F_CPU == 12800000
                break;  /* memory is tight at 12.8 MHz, save exit delay below */
#endif
                if(--i == 0){
                    if(--j == 0)
                        break;
                }
            }
#endif
        } while (bootLoaderCondition()  &&  (usbConfiguration != 0  ||  ovcnt < 100));
    }
    leaveBootloader();
}

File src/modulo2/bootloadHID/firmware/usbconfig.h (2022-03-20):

/* Name: usbconfig.h
 * Project: AVR USB driver
 * Author: Christian Starkjohann
 * Creation Date: 2007-03-13
 * Tabsize: 4
 * Copyright: (c) 2007 by OBJECTIVE DEVELOPMENT Software GmbH
 * License: GNU GPL v2 (see License.txt)
 * This Revision: $Id$
 */

#ifndef __usbconfig_h_included__
#define __usbconfig_h_included__

/*
General Description:
This file contains the configuration options for the USB driver.

Please note that the usbdrv contains a usbconfig-prototype.h file now. We
recommend that you use that file as a template because it will always list
the newest features and options.
*/

/* Fetch the hardware configuration from bootloaderconfig.h so that we have a
 * single file where hardware settings are stored.
 * Do not edit the functional settings below.
 */
#include "bootloaderconfig.h"

#define USB_PUBLIC static
/* Use the define above if you #include usbdrv.c instead of linking against it.
 * This technique saves a couple of bytes in flash memory.
 */

/* --------------------------- Functional Range ---------------------------- */

#define USB_CFG_HAVE_INTRIN_ENDPOINT    1
/* Define this to 1 if you want to compile a version with two endpoints: The
 * default control endpoint 0 and an interrupt-in endpoint 1.
 */
#define USB_CFG_HAVE_INTRIN_ENDPOINT3   0
/* Define this to 1 if you want to compile a version with three endpoints: The
 * default control endpoint 0, an interrupt-in endpoint 1 and an interrupt-in
 * endpoint 3. You must also enable endpoint 1 above.
 */
#define USB_CFG_SUPPRESS_INTR_CODE      1
/* Define this to 1 if you want to declare interrupt-in endpoints, but don't
 * want to send any data over them. If this macro is defined to 1, functions
 * usbSetInterrupt() and usbSetInterrupt3() are omitted. This is useful if
 * you need the interrupt-in endpoints in order to comply to an interface
 * (e.g. HID), but never want to send any data. This option saves a couple
 * of bytes in flash memory and the transmit buffers in RAM.
 */
#define USB_CFG_IMPLEMENT_HALT          0
/* Define this to 1 if you also want to implement the ENDPOINT_HALT feature
 * for endpoint 1 (interrupt endpoint). Although you may not need this feature,
 * it is required by the standard. We have made it a config option because it
 * bloats the code considerably.
 */
#define USB_CFG_INTR_POLL_INTERVAL      200
/* If you compile a version with endpoint 1 (interrupt-in), this is the poll
 * interval. The value is in milliseconds and must not be less than 10 ms for
 * low speed devices.
 */
#define USB_CFG_IS_SELF_POWERED         0
/* Define this to 1 if the device has its own power supply. Set it to 0 if the
 * device is powered from the USB bus.
 */
#define USB_CFG_MAX_BUS_POWER           100
/* Set this variable to the maximum USB bus power consumption of your device.
 * The value is in milliamperes. [It will be divided by two since USB
 * communicates power requirements in units of 2 mA.]
 */
#define USB_CFG_IMPLEMENT_FN_WRITE      1
/* Set this to 1 if you want usbFunctionWrite() to be called for control-out
 * transfers. Set it to 0 if you don't need it and want to save a couple of
 * bytes.
 */
#define USB_CFG_IMPLEMENT_FN_READ       0
/* Set this to 1 if you need to send control replies which are generated
 * "on the fly" when usbFunctionRead() is called. If you only want to send
 * data from a static buffer, set it to 0 and return the data from
 * usbFunctionSetup(). This saves a couple of bytes.
 */
#define USB_CFG_IMPLEMENT_FN_WRITEOUT   0
/* Define this to 1 if you want to use interrupt-out (or bulk out) endpoint 1.
 * You must implement the function usbFunctionWriteOut() which receives all
 * interrupt/bulk data sent to endpoint 1.
 */
#define USB_CFG_HAVE_FLOWCONTROL        0
/* Define this to 1 if you want flowcontrol over USB data. See the definition
 * of the macros usbDisableAllRequests() and usbEnableAllRequests() in
 * usbdrv.h.
 */
#define TIMER0_PRESCALING           64 /* must match the configuration for TIMER0 in main */
#define TOLERATED_DEVIATION_PPT     5  /* max clock deviation before we tune in 1/10 % */
/* derived constants: */
#define EXPECTED_TIMER0_INCREMENT   ((F_CPU / (1000 * TIMER0_PRESCALING)) & 0xff)
#define TOLERATED_DEVIATION         (TOLERATED_DEVIATION_PPT * F_CPU / (1000000 * TIMER0_PRESCALING))
#ifdef __ASSEMBLER__
macro tuneOsccal
    push    YH                              ;[0]
    clr     YH                              ;[2]
    in      YL, TCNT0                       ;[3]
    out     TCNT0, YH                       ;[4]
    subi    YL, EXPECTED_TIMER0_INCREMENT   ;[5]
#if OSCCAL > 0x3f
    lds     YH, OSCCAL                      ;[6]
#else
    in      YH, OSCCAL                      ;[6]
#endif
    cpi     YL, TOLERATED_DEVIATION + 1     ;[7]
    brmi    notTooHigh                      ;[8]
    subi    YH, 1                           ;[9] clock rate was too high
    rjmp    osctuneDone                     ;[10]
notTooHigh:
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

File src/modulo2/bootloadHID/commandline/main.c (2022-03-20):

/* Name: main.c
 * Project: AVR bootloader HID
 * Author: Christian Starkjohann
 * Creation Date: 2007-03-19
 * Tabsize: 4
 * Copyright: (c) 2007 by OBJECTIVE DEVELOPMENT Software GmbH
 * License: Proprietary, free under certain conditions. See Documentation.
 * This Revision: $Id$
 */

#include <stdio.h>
#include <string.h>
#include <stdlib.h>
#include <errno.h>
#include "usbcalls.h"

#define IDENT_VENDOR_NUM        0x16c0
#define IDENT_VENDOR_STRING     "nodep"
#define IDENT_PRODUCT_NUM       1503
#define IDENT_PRODUCT_STRING    "myAmpBL"

/* ------------------------------------------------------------------------- */

static char dataBuffer[65536 + 256];    /* buffer for file data */
static int  startAddress, endAddress;
static char leaveBootLoader = 0;

/* ------------------------------------------------------------------------- */

static int  parseUntilColon(FILE *fp)
{
int c;

    do{
        c = getc(fp);
    }while(c != ':' && c != EOF);
    return c;
}

static int  parseHex(FILE *fp, int numDigits)
{
int     i;
char    temp[9];

    for(i = 0; i < numDigits; i++)
        temp[i] = getc(fp);
    temp[i] = 0;
    return strtol(temp, NULL, 16);
}

/* ------------------------------------------------------------------------- */

static int  parseIntelHex(char *hexfile, char buffer[65536 + 256], int *startAddr, int *endAddr)
{
int     address, base, d, segment, i, lineLen, sum;
FILE    *input;

    input = fopen(hexfile, "r");
    if(input == NULL){
        fprintf(stderr, "error opening %s: %s\n", hexfile, strerror(errno));
        return 1;
    }
    while(parseUntilColon(input) == ':'){
        sum = 0;
        sum += lineLen = parseHex(input, 2);
        base = address = parseHex(input, 4);
        sum += address >> 8;
        sum += address;
        sum += segment = parseHex(input, 2);  /* segment value? */
        if(segment != 0)    /* ignore lines where this byte is not 0 */
            continue;
        for(i = 0; i < lineLen ; i++){
            d = parseHex(input, 2);
            buffer[address++] = d;
            sum += d;
        }
        sum += parseHex(input, 2);
        if((sum & 0xff) != 0){
            fprintf(stderr, "Warning: Checksum error between address 0x%x and 0x%x\n", base, address);
        }
        if(*startAddr > base)
            *startAddr = base;
        if(*endAddr < address)
            *endAddr = address;
    }
    fclose(input);
    return 0;
}

/* ------------------------------------------------------------------------- */

char    *usbErrorMessage(int errCode)
{
static char buffer[80];

    switch(errCode){
        case USB_ERROR_ACCESS:      return "Access to device denied";
        case USB_ERROR_NOTFOUND:    return "The specified device was not found";
        case USB_ERROR_BUSY:        return "The device is used by another application";
        case USB_ERROR_IO:          return "Communication error with device";
        default:
            sprintf(buffer, "Unknown USB error %d", errCode);
            return buffer;
    }
    return NULL;    /* not reached */
}

static int  getUsbInt(char *buffer, int numBytes)
{
int shift = 0, value = 0, i;

    for(i = 0; i < numBytes; i++){
        value |= ((int)*buffer & 0xff) << shift;
        shift += 8;
        buffer++;
    }
    return value;
}

static void setUsbInt(char *buffer, int value, int numBytes)
{
int i;

    for(i = 0; i < numBytes; i++){
        *buffer++ = value;
        value >>= 8;
    }
}

/* ------------------------------------------------------------------------- */

typedef struct deviceInfo{
    char    reportId;
    char    pageSize[2];
    char    flashSize[4];
}deviceInfo_t;

typedef struct deviceData{
    char    reportId;
    char    address[3];
    char    data[128];
}deviceData_t;

static int uploadData(char *dataBuffer, int startAddr, int endAddr)
{
usbDevice_t *dev = NULL;
int         err = 0, len, mask, pageSize, deviceSize;
union{
    char            bytes[1];
    deviceInfo_t    info;
    deviceData_t    data;
}           buffer;

    if((err = usbOpenDevice(&dev, IDENT_VENDOR_NUM, IDENT_VENDOR_STRING, IDENT_PRODUCT_NUM, IDENT_PRODUCT_STRING, 1)) != 0){
        fprintf(stderr, "Error opening HIDBoot device: %s\n", usbErrorMessage(err));
        goto errorOccurred;
    }
    len = sizeof(buffer);
    if(endAddr > startAddr){    // we need to upload data
        if((err = usbGetReport(dev, USB_HID_REPORT_TYPE_FEATURE, 1, buffer.bytes, &len)) != 0){
            fprintf(stderr, "Error reading page size: %s\n", usbErrorMessage(err));
            goto errorOccurred;
        }
        if(len < sizeof(buffer.info)){
            fprintf(stderr, "Not enough bytes in device info report (%d instead of %d)\n", len, (int)sizeof(buffer.info));
            err = -1;
            goto errorOccurred;
        }
        pageSize = getUsbInt(buffer.info.pageSize, 2);
        deviceSize = getUsbInt(buffer.info.flashSize, 4);
        printf("Page size   = %d (0x%x)\n", pageSize, pageSize);
        printf("Device size = %d (0x%x); %d bytes remaining\n", deviceSize, deviceSize, deviceSize - 2048);
        if(endAddr > deviceSize - 2048){
            fprintf(stderr, "Data (%d bytes) exceeds remaining flash size!\n", endAddr);
            err = -1;
            goto errorOccurred;
        }
        if(pageSize < 128){
            mask = 127;
        }else{
            mask = pageSize - 1;
        }
        startAddr &= ~mask;                  /* round down */
        endAddr = (endAddr + mask) & ~mask;  /* round up */
        printf("Uploading %d (0x%x) bytes starting at %d (0x%x)\n", endAddr - startAddr, endAddr - startAddr, startAddr, startAddr);
        while(startAddr < endAddr){
            buffer.data.reportId = 2;
            memcpy(buffer.data.data, dataBuffer + startAddr, 128);
            setUsbInt(buffer.data.address, startAddr, 3);
            printf("\r0x%05x ... 0x%05x", startAddr, startAddr + (int)sizeof(buffer.data.data));
            fflush(stdout);
            if((err = usbSetReport(dev, USB_HID_REPORT_TYPE_FEATURE, buffer.bytes, sizeof(buffer.data))) != 0){
                fprintf(stderr, "Error uploading data block: %s\n", usbErrorMessage(err));
                goto errorOccurred;
            }
            startAddr += sizeof(buffer.data.data);
        }
        printf("\n");
    }
    if(leaveBootLoader){
        /* and now leave boot loader: */
        buffer.info.reportId = 1;
        usbSetReport(dev, USB_HID_REPORT_TYPE_FEATURE, buffer.bytes, sizeof(buffer.info));
        /* Ignore errors here. If the device reboots before we poll the response,
         * this request fails.
         */
    }
errorOccurred:
    if(dev != NULL)
        usbCloseDevice(dev);
    return err;
}

/* ------------------------------------------------------------------------- */

static void printUsage(char *pname)
{
    fprintf(stderr, "usage: %s [-r] [<intel-hexfile>]\n", pname);
}
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

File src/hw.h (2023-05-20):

#pragma once

#include "iopin.h"
#include "timera.h"
#include "usart.h"
#include "spimaster.h"
#include "i2c.h"
#include "watch.h"

// screen & touchscreen
using s_led		= IoPin<'A', 7>;
using s_cs		= IoPin<'B', 0>;
using s_rst		= IoPin<'B', 1>;
using s_dc		= IoPin<'B', 2>;
using s_mosi	= IoPin<'B', 4>;
using s_miso	= IoPin<'B', 5>;
using s_sck		= IoPin<'B', 6>;

using ts_cs		= IoPin<'B', 3>;
using ts_irq	= IoPin<'B', 7>;

using s_spi		= SpiMaster<1, 6>;

// FV-1
using fv1_clip		= IoPin<'E', 6>;
using fv1_t0		= IoPin<'E', 7>;
using fv1_s0		= IoPin<'F', 4>;
using fv1_s1		= IoPin<'F', 5>;	// these two are swapped on the latest PCB version
using fv1_s2		= IoPin<'G', 3>;	// these two are swapped on the latest PCB version
using fv1_p0		= IoPin<'G', 0>;
using fv1_p1		= IoPin<'G', 1>;
using fv1_p2		= IoPin<'G', 2>;
using fv1_sda		= IoPin<'F', 2>;
using fv1_scl		= IoPin<'F', 3>;
using fv1_i2c		= I2CSlave<1>;

// digipot mix
using dp_mix_sda	= IoPin<'C', 2>;
using dp_mix_scl	= IoPin<'C', 3>;
using dp_mix_i2c	= I2CMaster<0>;

const uint8_t dp_mix_address = 0b101111;

// PWM for FV-1 pots
using fv1_pwm_timer	= TimerA<0, 1>;

// FV-1 knobs
using fv1k_led		= IoPin<'D', 3>;
using fv1k_re_a		= IoPin<'D', 4>;
using fv1k_re_sw	= IoPin<'D', 5>;
using fv1k_re_b		= IoPin<'D', 6>;
using fv1k_pot1		= IoPin<'E', 2>;
using fv1k_pot2		= IoPin<'E', 3>;
using fv1k_pot3		= IoPin<'E', 4>;
using fv1k_pot4		= IoPin<'E', 5>;

// power amp
using pa_fault		= IoPin<'A', 0>;
using pa_reset		= IoPin<'A', 1>;
using pa_mute		= IoPin<'A', 2>;
using pa_otw_clip	= IoPin<'G', 7>;

// pedals/footswitches UART
using pdl_tx		= IoPin<'E', 0>;
using pdl_rx		= IoPin<'E', 1>;
using pdl_usart		= Usart<4>;

// misc
using in_v			= IoPin<'D', 7>;
using dbg_tx		= IoPin<'A', 4>;
using dbg_pin		= IoPin<'A', 3>;

// timekeeping: 1 tick == 0.24ms
using Watch = RTClock<8>;

using DebugUsart = Usart<0>;

void init_hw();

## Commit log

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2020-02-17 added fender tone stack
    [myAmp.sch]
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2020-02-18 added power amp to schematic; added more footprints
    [myAmp.sch]
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2020-02-18 schematic done; PCB started
    [myAmp.kicad_pcb, myAmp.sch]
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2020-02-27 some 3D model references corrected
    [myAmp.kicad_pcb]
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2020-04-29 modular version in beta
    [myAmp.kicad_pcb, myAmp.sch]
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2020-05-14 this one was actually sent
    [myAmp.kicad_pcb, myAmp.sch]
2020-05-21 started routing FV-1 breakout
    [fv-1_breakout.kicad_pcb, fv-1_breakout.sch]
2020-05-25 came up with the name: RedMyst
    [RedMyst.kicad_pcb, RedMyst.sch]
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2020-05-30 added alps 3d models
    [RedMyst.kicad_pcb, RedMyst.sch, myAmp.sch]
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2020-06-01 layout done; starting routing
    [RedMyst.kicad_pcb, RedMyst.sch]
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2020-06-07 red myst (which is green) is routed... and abandoned
    [RedMyst.kicad_pcb]
2020-06-08 scrapped RedMyst; started modulo
    [RedMyst.kicad_pcb, modulo.kicad_pcb, modulo.sch]
2020-06-09 started routing the preamp
    [modulo.kicad_pcb, modulo.sch]
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2020-06-10 half way laying out the mixer
    [modulo-fv.sch, modulo-mcu.sch, modulo-mix.sch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]
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2020-06-14 small changes on pcb
    [modulo.kicad_pcb]
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2020-06-16 routing power & mcu
    [modulo-mcu.sch, modulo.kicad_pcb]
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2020-06-17 10k audio pot in the mixer
    [modulo-mix.sch, modulo.kicad_pcb]
2020-06-18 routed FV-1 and the mixer
    [modulo-fv.sch, modulo-mcu.sch, modulo-mix.sch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]
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2020-06-18 added pot and rotenc datasheets; cosmetics
    [modulo.kicad_pcb]
2020-06-19 ccw/cw on pots; new values of the tone stack
    [modulo-pa.sch, modulo.kicad_pcb]
2020-06-19 front copper plant; pot descriptions
    [modulo.kicad_pcb]
2020-06-21 this one goes to fab
    [modulo.kicad_pcb]
2020-06-23 fresh render; cosmetic changes in the mcu & power schematic
    [modulo-mcu.sch]
2020-07-27 AVR software started; small hardware problems fixed
    [modulo-fv.sch, modulo-mcu.sch, modulo-pa.sch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]
2020-07-29 fixed constant in refresh_program
    [main.c]
2021-11-21 Sent modulo2 power amp to PCB fab
    [modulo2-powamp.sch, modulo2.kicad_pcb, modulo2.sch]
2021-11-30 before rev 2 of the power amp
    [modulo2-eq.sch, modulo2-powamp.kicad_pcb, modulo2-powamp.sch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]
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2021-12-16 master volume with TMB tone stack; fv1 initial
    [modulo2-fv1.kicad_pcb, modulo2-fv1.sch, modulo2-master.kicad_pcb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]
2021-12-19 cleanup the the power amp a bit; still need to move the diff inputs
    [modulo2-master.kicad_pcb, modulo2-powamp.kicad_pcb]
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2022-01-03 master moved to kicad 6 (yikes!)
    [modulo2-master.kicad_pcb, modulo2-master.kicad_sch, modulo2-master.sch]
2022-01-03 moved last 3d models to project
    [modulo2-master.sch]
2022-01-07 added new preamp sim
    [modulo2-master.kicad_pcb, modulo2-master.kicad_sch]
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2022-01-11 redone layout and tracing
    [modulo2-pa27.kicad_pcb, modulo2-pa27.kicad_sch]
2022-01-15 made a toner transfer pa27
    [modulo2-pa27.kicad_pcb, modulo2-pa27.kicad_sch]
2022-01-31 made FV-1 prototype; converted kicad 5 files to kicad 6
    [modulo-fv.kicad_sch, modulo-fv.sch, modulo-mcu.kicad_sch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]
2022-02-04 FV-1 firmware reworked for the new board; FV-1 PCB needs rework to correct errors
    [modulo2-eq.kicad_sch, modulo2-fv1.kicad_pcb, modulo2-fv1.kicad_sch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]
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2022-02-06 added report on createBanks.py; started PCB redesign
    [modulo2-fv1.kicad_pcb, modulo2-fv1.kicad_sch, modulo2-pa27.kicad_pcb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]
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2022-02-07 routed pa27; routing fv-1
    [modulo2-fv1.kicad_pcb, modulo2-fv1.kicad_sch, modulo2-pa27.kicad_pcb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]
2022-02-09 further routing of FV-1
    [modulo2-fv1.kicad_pcb, modulo2-fv1.kicad_sch, modulo2-pa27.kicad_pcb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]
2022-02-09 no more assembler; more routing
    [modulo2-fv1.kicad_pcb, modulo2-fv1.kicad_sch, modulo2-pa27.kicad_pcb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]
2022-02-10 no more program banks; programs are now independent
    [modulo2-fv1.kicad_sch]
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2022-02-15 getting closer to the final PCBs; still have to change the rotenc
    [modulo2-fv1.kicad_pcb, modulo2-fv1.kicad_sch, modulo2-pa27.kicad_pcb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]
2022-02-16 found new switch for gain select; eq needs redesign
    [modulo2-aux.kicad_pcb, modulo2-aux.kicad_sch, modulo2-eq.kicad_pcb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]
2022-02-19 usb has been changed to accommodate fab capabilities; moved the rotenc deeper into the board
    [modulo2-fv1.kicad_pcb, modulo2-fv1.kicad_sch]
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2022-02-21 ditched the LED array board; LEDs are on the main PCB now
    [modulo2-aux.kicad_pcb, modulo2-aux.kicad_sch, modulo2-fv1.kicad_pcb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]
2022-02-22 tweaked program selector LEDs
    [modulo2-fv1.kicad_pcb, modulo2-fv1.kicad_sch]
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2022-03-16 added simple 3D render of PCBs for the enclosure
    [in_pedal.scad]
2022-03-20 fixed mistakes from assembly; added bootloader; firmware changed for PCB
    [in_pedal.scad, modulo2-fv1.kicad_pcb, modulo2-fv1.kicad_sch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]
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2022-03-21 updated 3d model (again)
    [in_pedal.scad]
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2022-03-25 bugfix in timer
2022-03-25 reduced preamp gain to not clip the FV-1; timer_ticks_high();
    [modulo2-pa27.kicad_pcb, modulo2-pa27.kicad_sch]
2022-03-26 LED flashing reworked
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2022-03-28 rotenc stabilize; fixed led_show() bug
    [main.c]
2022-03-28 bugfixes in rotary encoder
    [main.c]
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2022-04-15 power off brown-out removed
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2022-05-05 added inrush current sym; modulo3 box
    [modulo3.scad]
2022-09-14 reworked the cabinet model
    [modulo3.scad]
2022-09-20 asked for a quote on the cab(s)
    [modulo3.scad, modulo3_common.scad, modulo3_double.scad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]
2022-12-18 started modulo3; added FV-1 programs
    [modulo3-fv1.kicad_pcb, modulo3-fv1.kicad_sch, modulo3-mcu.kicad_pcb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]
2023-01-10 mcu board; fv1 board tracing
    [modulo3-fv1.kicad_pcb, modulo3-fv1.kicad_sch, modulo3-mcu.kicad_pcb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]
2023-01-13 added avr64da pinout table
    [avr64da pinouts.xlsx]
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2023-01-28 typo in pinout XL
    [avr64da pinouts.xlsx]
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2023-02-17 got the pcs and holes sizes for mcu, poweamp and fv1
    [modulo3-fv1.kicad_pcb, modulo3-fv1.kicad_sch, modulo3-mcu.kicad_pcb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]
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2023-04-23 updated zone fill edge on pa27; moved modulo2 source
    [modulo3-pa27.kicad_pcb]
2023-04-25 fixed p mosfet for screen LED; started src
    [modulo3-mcu.kicad_pcb, modulo3-mcu.kicad_sch]
2023-04-29 fixed blunder in pa27; added stubs for some of the source files
    [modulo3-pa27.kicad_pcb, modulo3-pa27.kicad_sch]
2023-05-01 lowered the watch resolution to .24 ms; moved the pins of the display; added pull-ups for mix i2c
    [modulo3-fv1.kicad_pcb, modulo3-mcu.kicad_pcb, modulo3-mcu.kicad_sch]
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2023-05-20 cleanup ADC and added noise gate
    [app.cpp]
2023-05-21 reverted adc::is_new(); started eeprom
    [app.cpp, main.cpp]
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2023-10-29 wet/dry is not correctly printed; fixed coordinate bug in text print
    [app.cpp, graphtext.h]
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2023-11-12 assembled and tested; power amp working; problem with noise from EXP pedal coupled into preamp/mix
    [app.cpp, fv1.cpp, main.cpp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]
2023-11-14 brown-out added; cleaned up some FV-1 programs
    [hw.cpp]
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2024-12-01 fixes with preset loading
    [fv1.cpp]

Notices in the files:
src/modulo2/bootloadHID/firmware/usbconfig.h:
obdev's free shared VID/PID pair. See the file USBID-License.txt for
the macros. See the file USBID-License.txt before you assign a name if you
